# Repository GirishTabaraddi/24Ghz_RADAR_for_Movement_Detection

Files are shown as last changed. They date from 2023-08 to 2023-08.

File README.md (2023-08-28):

# 24Ghz_RADAR_for_Movement_Detection

This Project describes the Movement Detection using 24GHz CW-RADAR sensor which was performed in the System Driven Hardware Design Lab as a lab group.

KiCad_LabProject - This folder contains all the schematic and pcb files.
				 - 10_work folder contains the recent files of the project schematic.
				 - 20_release folder contains all the previous versions of the circuit design.

SDHD_PSoC_Codes - This folder contains all the project codes for various lab assigments and final code of the movement detector Project

SDHD_Lab3_FFT.cydsn - This workspace inside the SDHD_PSoC_Codes is the main code required for executing the Movement Detection.

Project Report pdf and ppt are added for reference to understand how the project was performed in the lab during summer semester.

This Project was carried at Hochschule Darmstadt during Summer semester 2023.
Other contributors are: Drashti Shah and Ananya Harish.

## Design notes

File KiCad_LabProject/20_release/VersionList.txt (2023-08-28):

17.04.2023, GROUP D3
Project: Movement Detector based on IPM-165 Radar Module
------------------------------------------------------------------------

17.04.2023 - Movement Detector based on IPM-165 Radar Module, Vesion 1.0
------------------------------------------------------------------------
Features:
		1. Schematic of 4th order Bandpass filter.
		2. Includes all the necessary calculations.
		3. Footprint Assignments to all the components.

19.04.2023 - Movement Detector based on IPM-165 Radar Module, Vesion 1.1
------------------------------------------------------------------------
Features:
		1. Schematic of 4th order Bandpass filter modified due 
			to mil errors in the previous schematic.
		2. Added Star ground connection, SW Push button and 
			90° 3 Pin connector.
		3. Necessary footprints assigned to all the components.

26.04.2023 - Movement Detector based on IPM-165 Radar Module, Vesion 1.2
------------------------------------------------------------------------
Features:
		1. Schematic of 4th order Bandpass filter modified as 
			per the feedback from first lab.
		2. Removed all ground differentiations like analog, 
			digital grounds and made only one commmon ground for all circuits.
		3. Removed star ground connection.
		4. Assigned correct footprints to all components as per the datasheets.
		5. Added +5v at all points.

03.05.2023 - Movement Detector based on IPM-165 Radar Module, Vesion 1.3
------------------------------------------------------------------------
Features:
		1. Few updates on the footprints.
		2. Placed all the components on PCB layout and routed all the components.
		3. Layer 1 and 4 are common ground.

13.05.2023 - Movement Detector based on IPM-165 Radar Module, Vesion 1.4
------------------------------------------------------------------------
Features:
		1. Replaced the components for better design and short distance
			from sensor to Vin.
		2. Added vias for GND.
		3. Connected SW_Push to GND (Pull-up network).
		4. Added +5V and GND naming to 3 Pin connector for better readability.

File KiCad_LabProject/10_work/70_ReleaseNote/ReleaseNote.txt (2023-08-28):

17.04.2023, GROUP D3
Project: Movement Detector based on IPM-165 Radar Module
---------------------------------------------------------------

v1.0: 17.04.2023
###############################################################
Features:
		1. Schematic of 4th order Bandpass filter.
		2. Includes all the necessary calculations.
		3. Footprint Assignments to all the components.
		 
v1.1: 19.04.2023
###############################################################
Features:
		1. Schematic of 4th order Bandpass filter modified due 
			to mil errors in the previous schematic.
		2. Added Star ground connection, SW Push button and 
			90° 3 Pin connector.
		3. Necessary footprints assigned to all the components.
		
v1.2: 26.04.2023
###############################################################
Features:
		1. Schematic of 4th order Bandpass filter modified as 
			per the feedback from first lab.
		2. Removed all ground differentiations like analog, 
			digital grounds and made only one commmon ground for all circuits.
		3. Removed star ground connection.
		4. Assigned correct footprints to all components as per the datasheets.
		5. Added +5v at all points.
		
v1.3 03.05.2023
###############################################################
Features:
		1. Few updates on the footprints.
		2. Placed all the components on PCB layout and routed all the components.
		3. Layer 1 and 4 are common ground.

v1.4 13.05.2023
###############################################################
Features:
		1. Replaced the components for better design and short distance
			from sensor to Vin.
		2. Added vias for GND.
		3. Connected SW_Push to GND (Pull-up network).
		4. Added +5V and GND naming to 3 Pin connector for better readability.

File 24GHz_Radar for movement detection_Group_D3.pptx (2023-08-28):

## 24GHz-Radar for movement detection

- Group number: d3
- Members:
Girish Tabaraddi 1119236
Drashti shah 1119295
Ananya harish 1119248

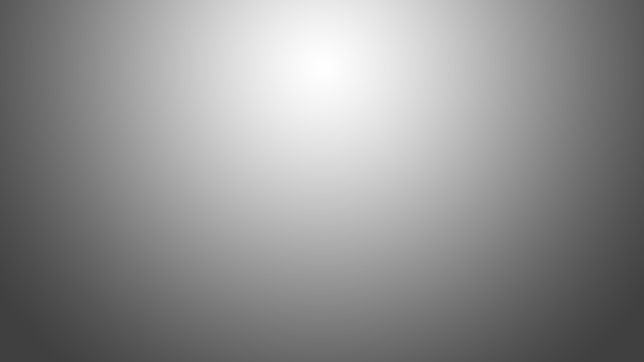
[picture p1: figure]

## Content

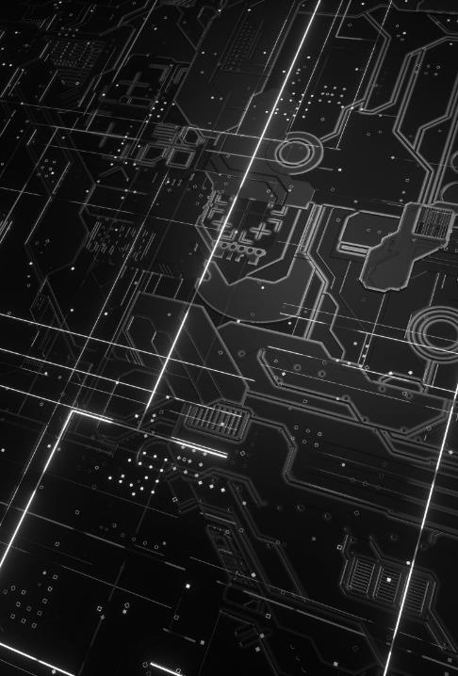
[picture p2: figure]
Abstract technological connection

- Introduction
- Block Diagram
- Schematic and PCB design
- 3D View and Soldered PCB
- State Machine
- Software Code
- Breadboard connections
- Hardware Testing
- CFAR algorithm

## INTRODUCTION:

- A 24 GHz radar sensor detects movements and send Doppler frequency to bandpass filter if the movement is detected.
- The 4th order Bandpass filter gives Baseband signal as the output which in-turn is send to the ADC.
- PSOC samples ADC and FFT data and sends it to MATLAB.
- We are using CFAR to set a threshold with which the probability of false alarm reduces.

## BLOCK DIAGRAM

RADAR MODULE

Amplifier

Band pass filter

ADC

LED

Detector

CFAR

FFT

## Schematic and pcb design

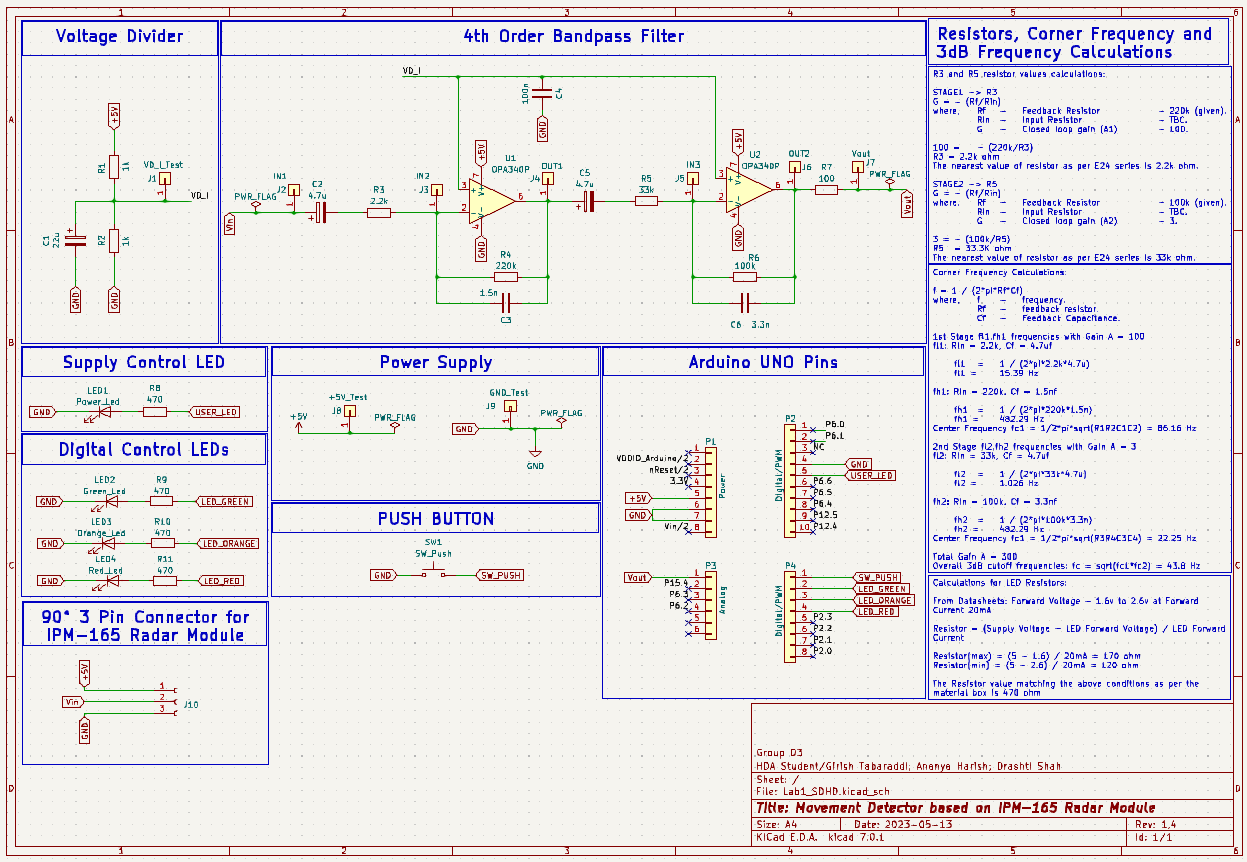
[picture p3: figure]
A computer screen shot of a diagram

Fig 1. PCB SCHEMATIC VIEW

## 3D view and soldered PCB

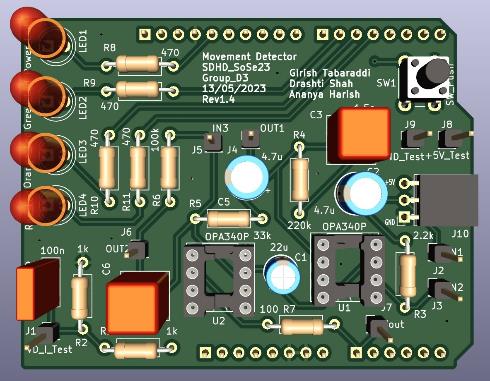
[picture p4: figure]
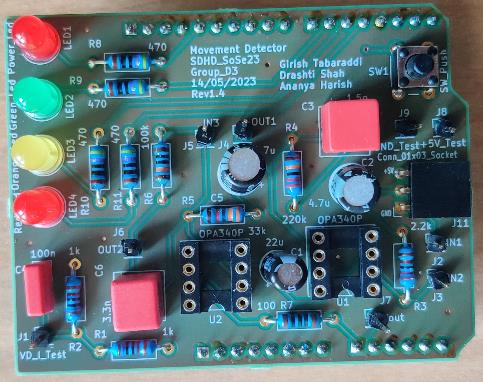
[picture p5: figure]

Fig 3. PCB TOP VIEW

Fig 2. PCB 3D VIEW

## STATE MACHINE

Fig 4. State Machine

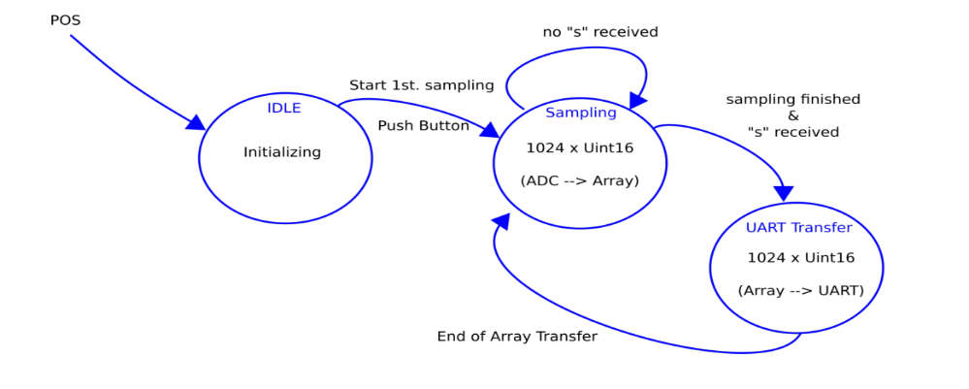
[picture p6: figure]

## SOFTWARE CODE

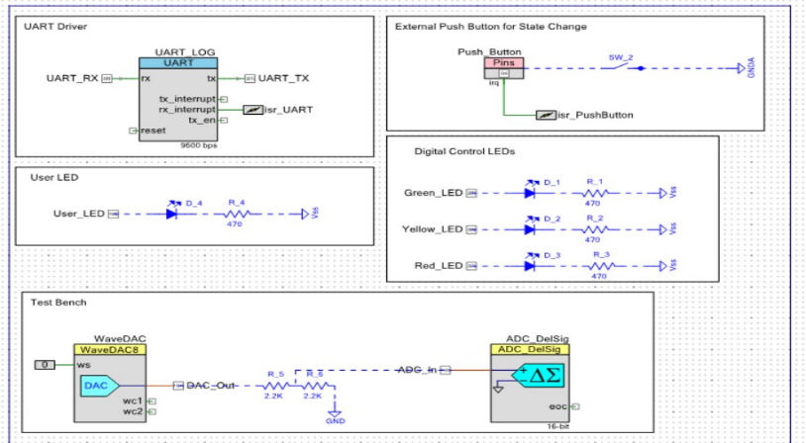
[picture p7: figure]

Fig 5. TOP DESIGN

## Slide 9

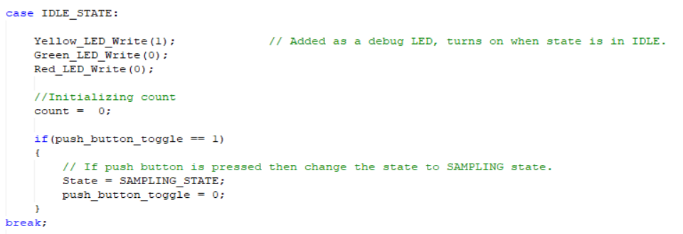
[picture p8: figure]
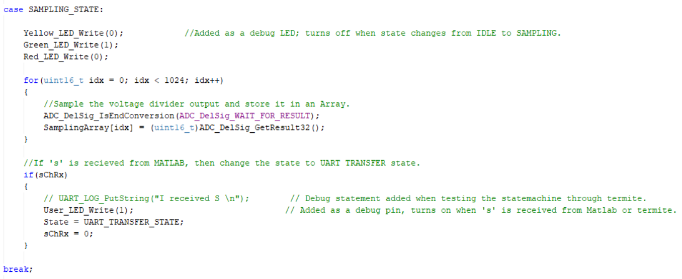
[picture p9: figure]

Fig 6. IDLE STATE

Fig 7. SAMPLING STATE

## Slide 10

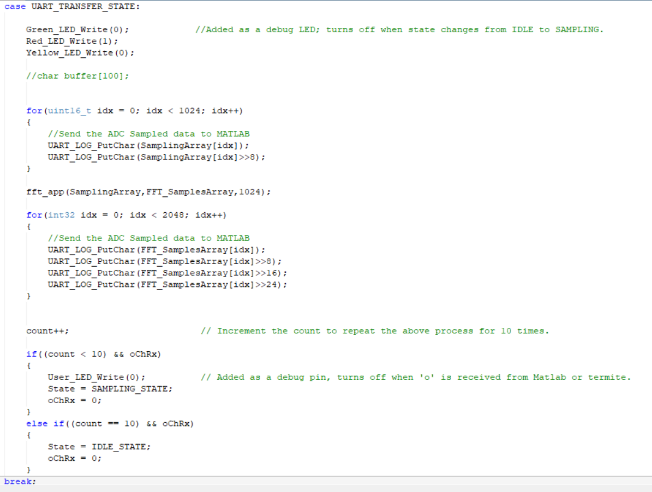
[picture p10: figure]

Fig 8. UART TRANSFER STATE

## Matlab output

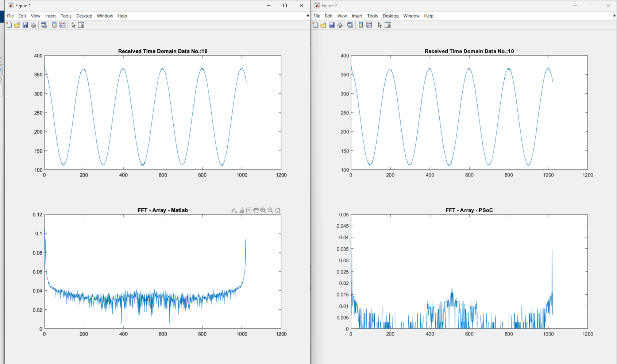
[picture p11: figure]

Fig 9. Matlab FFT Output

## Breadboard connections

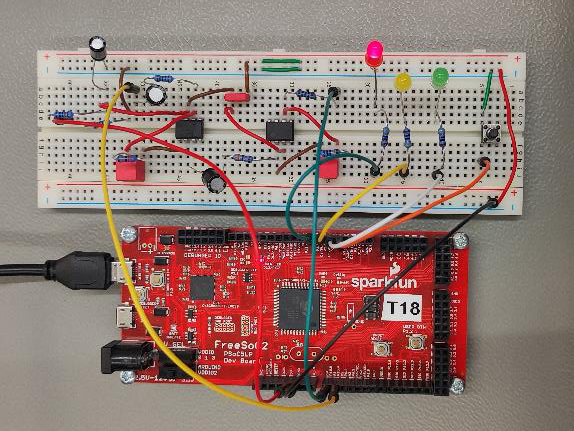
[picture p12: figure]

Fig 10. 4th Order Bandpass filter

## Hardware testing

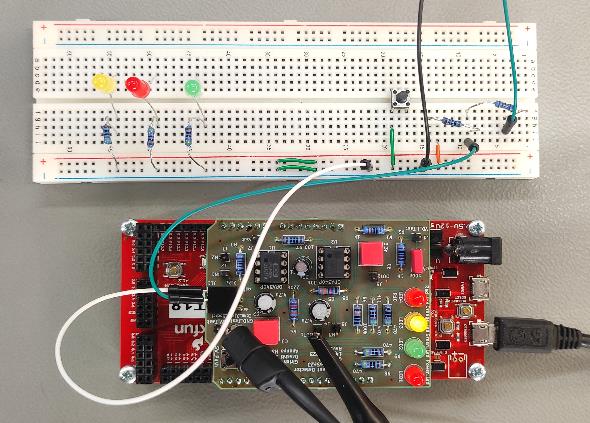
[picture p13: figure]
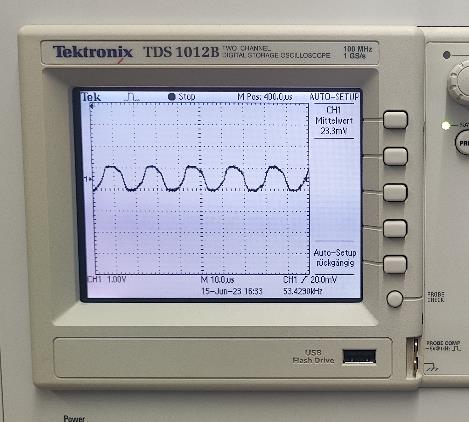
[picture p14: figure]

Fig 12. 1st Stage Circuit Output

Fig 11. 1st Stage Circuit

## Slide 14

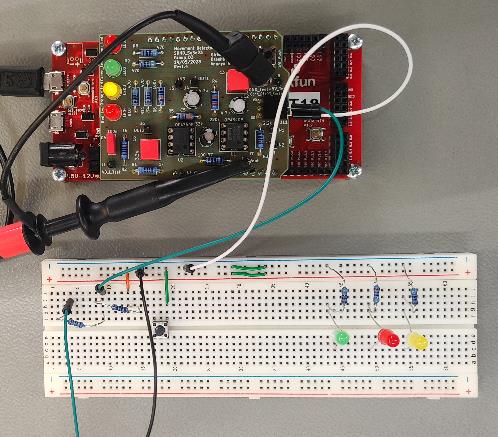
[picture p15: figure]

Fig 13. Final PCB Connection

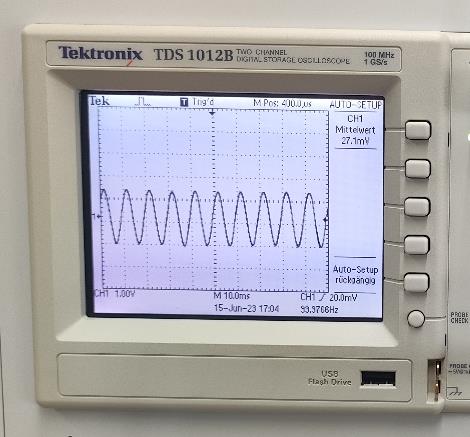
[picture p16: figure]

Fig 14. Final Output with Gain 300 dB

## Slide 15

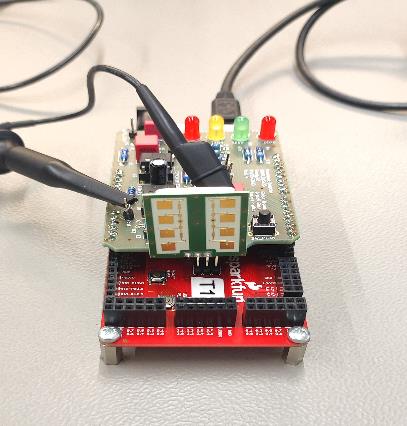
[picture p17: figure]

Fig 15. PCB with CW Radar Sensor

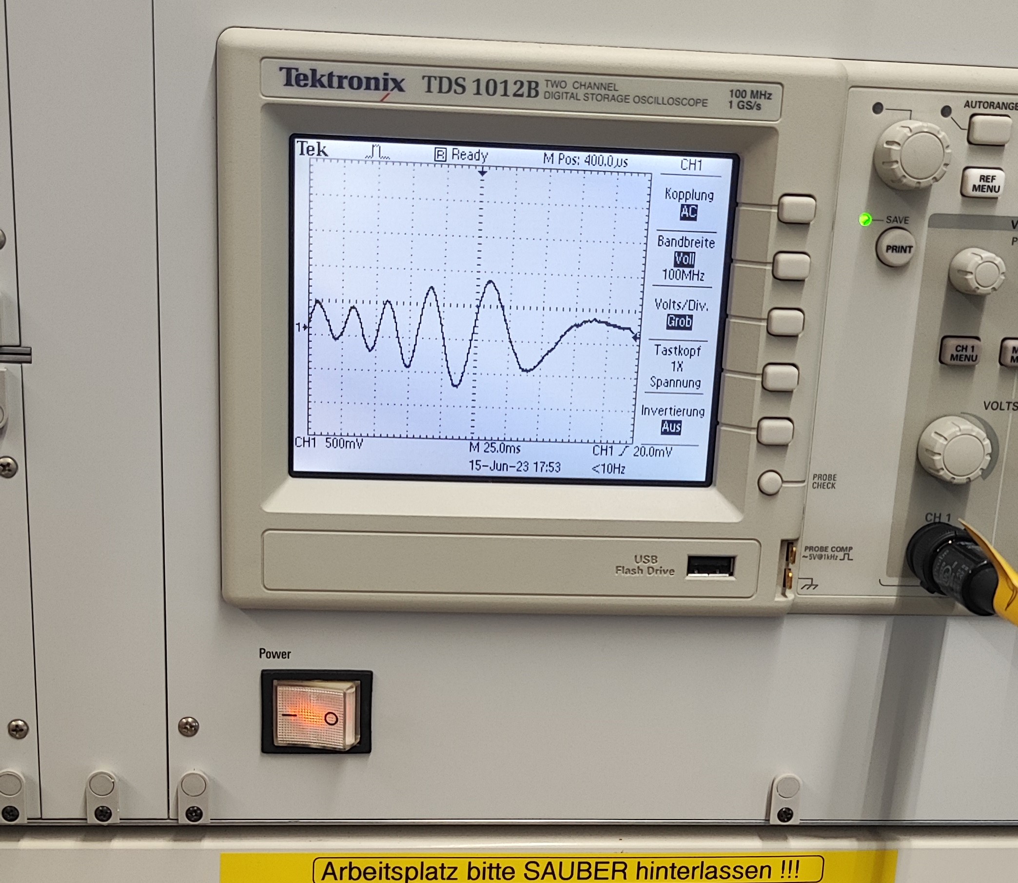
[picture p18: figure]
A white electronic device with a screen

Fig 16. Output

## CFAR Algorithm

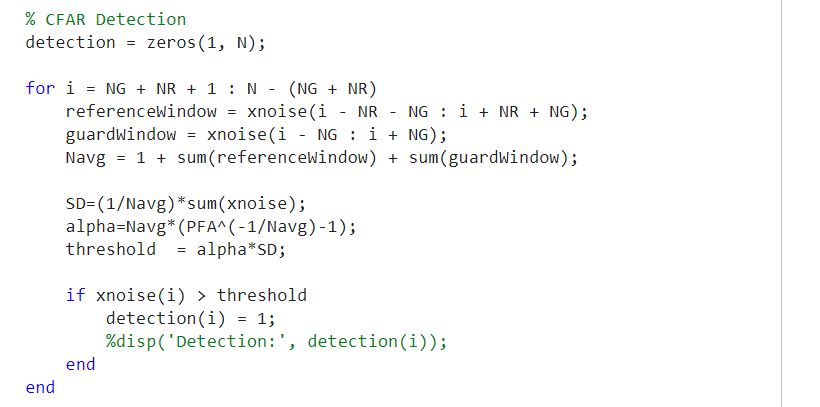
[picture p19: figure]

Fig 17. CFAR Algorithm

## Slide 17

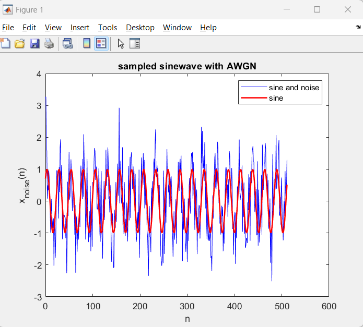
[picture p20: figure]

Fig 18. Signal+Noise

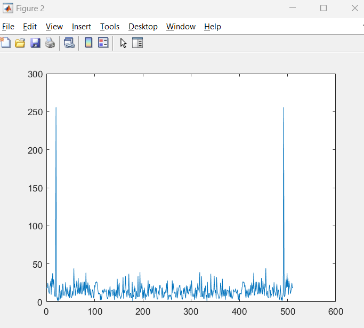
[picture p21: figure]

Fig 20. FFT of Signal+Noise

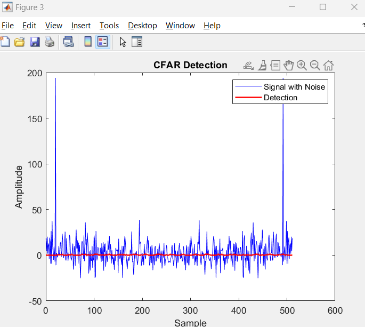
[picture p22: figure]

Fig 19. CFAR Detection

## THANK YOU

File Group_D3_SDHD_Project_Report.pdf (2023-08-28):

P r o j e c t R e p o r t
G r o u p D 3

2 4 G h z - R A D A R fo r
M o v e m e n t D e t e c t i o n

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

# 24Ghz-RADAR for Movement Detection Group D3 Project Documentation

Lab
Instructors: Mr. Holger Wech
Mr. Manuel Leidel

This Document describes the Movement Detection using 24GHz CW-RADAR sensor which was performed in the System Driven Hardware Design Lab as a lab group.

Author: | Ananya Harish | Communications | 1119248
Drashti Shah | Embedded Systems 1119295

Girish Tabaraddi Embedded Systems 1119236

Status: | released
Revision | Date | Editor | Reason
v1.0 | 02/July/2023 | Group D3 | Basic content and formatting

File: D3_SDHD_Project_Report | © Mimir – For Internal Use Only | Page 2 of 26
1.2.2 | 4

File: D3_SDHD_Project_Report | © Mimir – For Internal Use Only | Page 3 of 26


File: D3_SDHD_Project_Report | © Mimir – For Internal Use Only | Page 4 of 26

### 1 KiCad Schematic

The necessary schematic of Movement Detection using IPM-165 radar module is designed using KiCad 7.0 open-source free software.

### 1.1 Overall Schematic

- Clearly separated designs with Global Labels/Flags.
- Arduino shield was added for mounting of the amplifier on the FreeSoC board.
- 2 Stage Amplifier Design.
- Extra test points for easy debugging.
- LEDs to indicate the status of State Machine.

Fig.1 KiCad Schematic

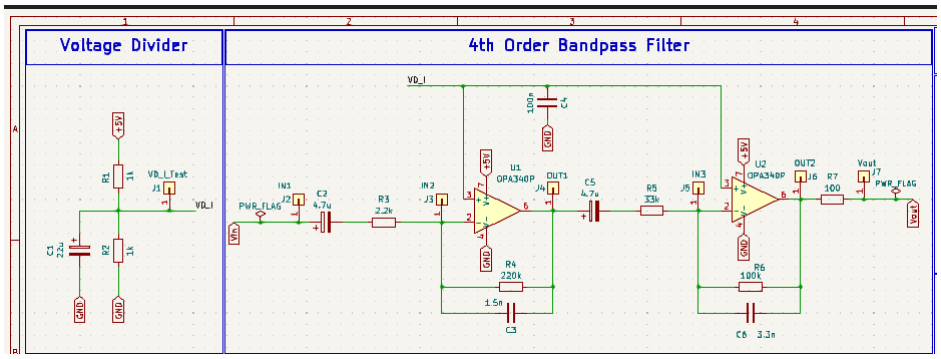
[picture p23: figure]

File: D3_SDHD_Project_Report | © Mimir – For Internal Use Only | Page 5 of 26

### 1.2 Analog Circuit

Fig 2. Voltage Divider and Bandpass Filter

### 1.2.1 Voltage Divider Circuit

Voltage Divider circuit is used to cut down the 5V given from the FreeSoC board to the non-inverting terminals of both the op-amps U1 & U2. The voltage is reduced to 2.5V, because the resistors selected have equal value (1kΩ each).

1.2.2 4

th Order Bandpass Filter

Vin (output of the radar module) is fed as the input to inverting terminal of the OPA-340 U1. The voltage range of the radar sensor is -300mV to 300mV. The circuit is designed to have a total gain of 300, which is divided into gain of 100 for the first stage amplifier and a gain of 3 for the second stage of the amplifier. Each of the circuit stages has their own test points for easy debugging and testing. The output of the amplifier circuit is passed on to the 16-bit ADC of PSOC board.

Fig 3. R3 and R5 resistor calculations.

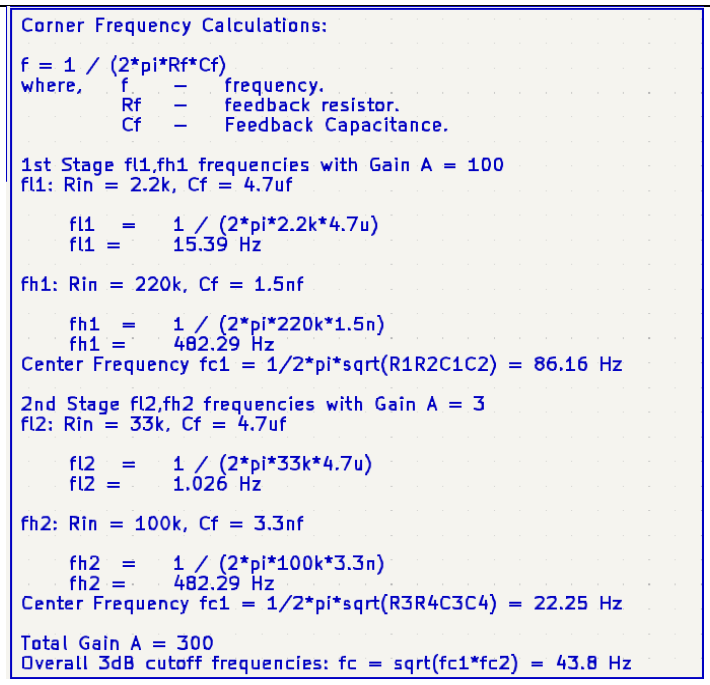
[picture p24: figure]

File: D3_SDHD_Project_Report | © Mimir – For Internal Use Only | Page 6 of 26

Fig 4. Corner Frequency Calculations.

### 1.3 Digital Circuit

Push Button is used to change from initial state to sampling state in software implementation, which is explained later in the following sections.
Similarly, the LEDs are added to visually notice the change of states. The Supply control LED is added in the design to ensure that the PCB is powered up.
Fig 5. Push Button. | Fig 6. Digital LEDs for State-machine.


File: D3_SDHD_Project_Report | © Mimir – For Internal Use Only | Page 7 of 26

Fig 7. LED Resistor Calculations.

### 1.4 Power Supply

Power flags and global naming flags ared added for convenience. Sufficient test points are added in the circuit for easy debugging and testing.

Fig 8. Power Supply Connection.


File: D3_SDHD_Project_Report | © Mimir – For Internal Use Only | Page 8 of 26

### 1.5 IPM-165 Radar Module

The IPM-165 is a 24GHz doppler module with an asymmetrical wide beam for detection of moving objects. Pin 1 of the sensor is used to power up the radar module, Pin 2 is used to give input to the bandpass filter and Pin 3 is connected to the ground.

Fig 9. IPM-165 Radar Module

### 1.6 Interface to FreeSoC Board

To integrate our circuit to the FreeSoC board, we need the Arduino UNO shield which matches the FreeSoC pins. So, we imported the Arduino UNO shield from KiCad inbuilt library and the necessary pin mapping is provided in the following figure.

Fig 10. Arduino UNO Shield pin mapping.


File: D3_SDHD_Project_Report | © Mimir – For Internal Use Only | Page 9 of 26

### 2 PCB Design

### 2.1 About PCB

Our PCB has a thickness of 1.6mm and consists of four layers. Four layers PCB means there are 4 layers to rout electrical signals: Top Layer, Inner Layer 1, Inner Layer 2 and Bottom Layer. TOP and bottom layers are the outer layers where we are placing components and routing. Inner layer 1 and inner layer 2 are in the core, and normally used as power planes or used for signal routing. Therefore, 4-layer PCB = 3 Signal layer + GND layer or 4-layer PCB = 2 signal layers + a VCC layer + a GND layer [Reference: https://www.allpcb.com/4_layer_pcb.html].

### 2.2 Layer 1

On this layer all signals and the components are placed. On the top and bottom layer, ground is poured to provide insulation. Vias are added to connect the ground layers on top and bottom together.

Fig 11. Front Signal Layer with routing


File: D3_SDHD_Project_Report | © Mimir – For Internal Use Only | Page 10 of 26

### 2.3 Layer 2

Ground is poured here.

Fig 12. Ground Layer

### 2.4 Layer 3

Here the VCC is poured over the third layer.

Fig 13. Power Layer


File: D3_SDHD_Project_Report | © Mimir – For Internal Use Only | Page 11 of 26

### 2.5 Layer 4

In order to avoid crossings of routing in first layer, the crossings are connected in the fourth layer. Vias are added to connect first and fourth layer.

Fig 14. Bottom Signal Layer with routing

2.6 3D view of PCB

The 3D view of the designed PCB is shown in the below figure. The minimum tract length between the input of the Radar and to the input of the IC is worked out.

Fig 15. 3D View

### 3 Hardware Connections


File: D3_SDHD_Project_Report | © Mimir – For Internal Use Only | Page 12 of 26

### 3.1 Stage 1 circuit connection

The connections of the first stage from the PCB are verified at test point J4(OUT1). An additional voltage divider circuit is connected to the PCB externally in order to reduce the input voltage such that the output voltage remains in the given range. For testing, we considered Vin of 200mV which was cut down to 8mV using resistors of 2.2kΩ and 100Ω. The gain of the first stage designed is 100 and the same was verified by obtaining an output voltage of 0.8V. The connection and output are as shown below.

Fig 16. First stage connection.

Fig 17. First stage output.


File: D3_SDHD_Project_Report | © Mimir – For Internal Use Only | Page 13 of 26

3.2 2 Stage circuit connection

The connections of the second stage from the PCB are verified at test point J7(VOUT). For the Vin of 200mV which was cut down to 8mV using resistors of 2.2kΩ and 100Ω at first stage. For the second stage with design of gain 3, the output was verified by obtaining 2.4V output voltage. The connection and output are as shown below.

Fig 18. Second stage connection.

Fig 19. Second stage output.


File: D3_SDHD_Project_Report | © Mimir – For Internal Use Only | Page 14 of 26

### 3.3 PCB with IPM-165 Radar Module

The IPM-165 Radar module is connected to the working PCB in order to detect the movement of a moving object. From the output it can be observed that the movement is detected by change of frequency as well as amplitude of the signal.

Fig 20. PCB with radar module

Fig 21. Radar module output

### 4 Software


File: D3_SDHD_Project_Report | © Mimir – For Internal Use Only | Page 15 of 26

### 4.1 Top Design for State-machine

Fig 22. Top Design

Fig 23. Pin mapping


File: D3_SDHD_Project_Report | © Mimir – For Internal Use Only | Page 16 of 26

### 4.1.1 ADC

Fig 24. ADC Configuration

### 4.1.2 DAC

Fig 25. DAC Configuration


File: D3_SDHD_Project_Report | © Mimir – For Internal Use Only | Page 17 of 26

### 4.1.3 UART

Fig 26. UART Configuration

### 4.2 State Diagram

Fig 27. State Diagram


File: D3_SDHD_Project_Report | © Mimir – For Internal Use Only | Page 18 of 26

### 4.3 State-machine Code

### 4.3.1 Hardware Initialization

Fig 28. Hardware Init Function

### 4.3.2 ISR functions

Fig 29. ISR Function definiton


File: D3_SDHD_Project_Report | © Mimir – For Internal Use Only | Page 19 of 26

### 4.3.3 Idle State

Fig 30. Idle State logic

### 4.3.4 Sampling State

Fig 31. Sampling State logic


File: D3_SDHD_Project_Report | © Mimir – For Internal Use Only | Page 20 of 26

### 4.3.5 UART Transfer State

Fig 32. UART Transfer State logic


File: D3_SDHD_Project_Report | © Mimir – For Internal Use Only | Page 21 of 26

### 4.4 Matlab Code & Output

Fig 33. MATLAB Script

Fig 34. MATLAB FFT Output

### 5 CFAR Algorithm


File: D3_SDHD_Project_Report | © Mimir – For Internal Use Only | Page 22 of 26

### 5.1 Target detection

A threshold is calculated and set in order to detect a signal and differentiate it with respect to noise. This in turn is used to reduce the probability of false alarm detection.

The following probabilities are used:
PD: A target is declared when a target is in fact present – Detection.
PM: A target is not declared when a target is in fact present – Missed. PFA: A target is declared when a target is in fact not present – False alarm.

Formula to calculate threshold:

The probability of detection is calculated using:

### 5.2 CFAR Code

Fig 35. CFAR Algorithm Script


File: D3_SDHD_Project_Report | © Mimir – For Internal Use Only | Page 23 of 26

### 5.3 CFAR Output

Fig 36. Signal + Noise Waveform

Fig 37. FFT of Signal + Noise


File: D3_SDHD_Project_Report | © Mimir – For Internal Use Only | Page 24 of 26

Fig 38. CFAR Detection

### 6 Manufactured & Soldered PCB


File: D3_SDHD_Project_Report | © Mimir – For Internal Use Only | Page 25 of 26

Fig 39. Unsoldered PCB

Fig 40. Soldered PCB Top View

File: D3_SDHD_Project_Report | © Mimir – For Internal Use Only | Page 26 of 26

### 7 References:

1. SDHD Lecture Slides
2. www.mathworks.com
3. https://mimir.h-da.io/public/index.htm
4. PSoC Getting Started by Thomas Barth
5. Embedded Architectures and Operating Systems Workbook (v2020a) by Prof. Dr.-Ing. Peter Fromm
6. https://www.sparkfun.com/products/13714
7. https://www.infineon.com/dgdl/Infineon-KitProg_User_Guide-UserManual-v01_00-EN.pdf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

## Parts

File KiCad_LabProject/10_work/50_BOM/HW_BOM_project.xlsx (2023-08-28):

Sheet: History
<Template Name - Achtung: Header und Footer Setzen>
<Department>
<ProjectName>
Author: | Name/Department
Status: | draft/release/obsolete
History
Revision | Date | Author | Reason

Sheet: Instructions
Field | Description

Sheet: content_page
Date: | 2023-05-03 12:16
Revision: | 1.3
Component Count: | 3
Number of Boards: | 6.00
 | Single Board |  |  |  | Order |  |  |  | Notes
Ref | Value | Qnty | Vendor | Order No. | Component Name | Order Qnty | single price | Total price | Footprint | Description
C1 | 22u | 1 | Reichelt | RAD FR 22/50 | C_Polarized | 1 | 0.08 € | 0.08 € | Capacitor_THT:CP_Radial_D5.0mm_P2.50mm | Polarized capacitor
C2, C5 | 4.7u | 2 | Reichelt | SM 4,7/50RAD | C_Polarized | 2 | 0.08 € | 0.16 € | Capacitor_THT:CP_Radial_D6.3mm_P2.50mm | Polarized capacitor
C3 | 1.5n | 1 | Reichelt | FKP2-1000 1,5N | C | 1 | 0.08 € | 0.08 € | Capacitor_THT:C_Rect_L7.2mm_W7.2mm_P5.00mm_FKS2_FKP2_MKS2_MKP2 | Unpolarized capacitor
C4 | 100n | 1 | Reichelt | MKS2-100 100N | C | 1 | 0.08 € | 0.08 € | Capacitor_THT:C_Rect_L7.2mm_W2.5mm_P5.00mm_FKS2_FKP2_MKS2_MKP2 | Unpolarized capacitor
C6 | 3.3n | 1 | Reichelt | FKP2-630 3,3N | C | 1 | 0.08 € | 0.08 € | Capacitor_THT:C_Rect_L7.2mm_W7.2mm_P5.00mm_FKS2_FKP2_MKS2_MKP2 | Unpolarized capacitor
J1, J2 | ~ | 2 |  |  | Conn_01x01 | 2 |  |  | Connector_PinHeader_2.54mm:PinHeader_1x01_P2.54mm_Vertical | Generic connector, single row, 01x01, script generated (kicad-library-utils/schlib/autogen/connector/)
J3 | IN1 | 1 |  |  | Conn_01x01 | 1 |  |  | Connector_PinHeader_2.54mm:PinHeader_1x01_P2.54mm_Vertical | Generic connector, single row, 01x01, script generated (kicad-library-utils/schlib/autogen/connector/)
J4 | IN2 | 1 |  |  | Conn_01x01 | 1 |  |  | Connector_PinHeader_2.54mm:PinHeader_1x01_P2.54mm_Vertical | Generic connector, single row, 01x01, script generated (kicad-library-utils/schlib/autogen/connector/)
J5 | OUT1 | 1 |  |  | Conn_01x01 | 1 |  |  | Connector_PinHeader_2.54mm:PinHeader_1x01_P2.54mm_Vertical | Generic connector, single row, 01x01, script generated (kicad-library-utils/schlib/autogen/connector/)
J6 | IN3 | 1 |  |  | Conn_01x01 | 1 |  |  | Connector_PinHeader_2.54mm:PinHeader_1x01_P2.54mm_Vertical | Generic connector, single row, 01x01, script generated (kicad-library-utils/schlib/autogen/connector/)
J7 | OUT2 | 1 |  |  | Conn_01x01 | 1 |  |  | Connector_PinHeader_2.54mm:PinHeader_1x01_P2.54mm_Vertical | Generic connector, single row, 01x01, script generated (kicad-library-utils/schlib/autogen/connector/)
J8 | Vout | 1 |  |  | Conn_01x01 | 1 |  |  | Connector_PinHeader_2.54mm:PinHeader_1x01_P2.54mm_Vertical | Generic connector, single row, 01x01, script generated (kicad-library-utils/schlib/autogen/connector/)
J9 | +5V_Test | 1 |  |  | Conn_01x01 | 1 |  |  | Connector_PinHeader_2.54mm:PinHeader_1x01_P2.54mm_Vertical | Generic connector, single row, 01x01, script generated (kicad-library-utils/schlib/autogen/connector/)
J10 | GND_Test | 1 |  |  | Conn_01x01 | 1 |  |  | Connector_PinHeader_2.54mm:PinHeader_1x01_P2.54mm_Vertical | Generic connector, single row, 01x01, script generated (kicad-library-utils/schlib/autogen/connector/)
J11 | Conn_01x03_Socket | 1 |  |  | Conn_01x03_Socket | 1 |  |  | Connector_PinSocket_2.54mm:PinSocket_1x03_P2.54mm_Horizontal | Generic connector, single row, 01x03, script generated
LED1 | Power_Led | 1 | Distrelec | 301-32-217 | LED | 1 |  |  | LED_THT:LED_D5.0mm | Light emitting diode
LED2 | Green_Led | 1 | Distrelec | 301-32-225 | LED | 1 |  |  | LED_THT:LED_D5.0mm | Light emitting diode
LED3 | Orange_Led | 1 | Distrelec | 301-32-218 | LED | 1 |  |  | LED_THT:LED_D5.0mm | Light emitting diode
LED4 | Red_Led | 1 | Distrelec | 301-32-217 | LED | 1 |  |  | LED_THT:LED_D5.0mm | Light emitting diode
P1 | Power | 1 |  |  | Conn_01x08 | 1 |  |  | Connector_PinSocket_2.54mm:PinSocket_1x08_P2.54mm_Vertical | Generic connector, single row, 01x08, script generated (kicad-library-utils/schlib/autogen/connector/)
P2 | Digital/PWM | 1 |  |  | Conn_01x10 | 1 |  |  | Connector_PinSocket_2.54mm:PinSocket_1x10_P2.54mm_Vertical | Generic connector, single row, 01x10, script generated (kicad-library-utils/schlib/autogen/connector/)
P3 | Analog | 1 |  |  | Conn_01x06 | 1 |  |  | Connector_PinSocket_2.54mm:PinSocket_1x06_P2.54mm_Vertical | Generic connector, single row, 01x06, script generated (kicad-library-utils/schlib/autogen/connector/)
P4 | Digital/PWM | 1 |  |  | Conn_01x08 | 1 |  |  | Connector_PinSocket_2.54mm:PinSocket_1x08_P2.54mm_Vertical | Generic connector, single row, 01x08, script generated (kicad-library-utils/schlib/autogen/connector/)
R1, R2 | 1k | 2 | Reichelt | METALL 1,00K | R | 2 | 0.17 € | 0.34 € | Resistor_THT:R_Axial_DIN0207_L6.3mm_D2.5mm_P10.16mm_Horizontal | Resistor
R3 | 2.2k | 1 | Reichelt | METALL 2,20K | R | 1 | 0.17 € | 0.17 € | Resistor_THT:R_Axial_DIN0207_L6.3mm_D2.5mm_P10.16mm_Horizontal | Resistor
R4 | 220k | 1 | Reichelt | METALL 220K | R | 1 | 0.10 € | 0.10 € | Resistor_THT:R_Axial_DIN0207_L6.3mm_D2.5mm_P10.16mm_Horizontal | Resistor
R5 | 33k | 1 | Reichelt | METALL 33,0K | R | 1 | 0.17 € | 0.17 € | Resistor_THT:R_Axial_DIN0207_L6.3mm_D2.5mm_P10.16mm_Horizontal | Resistor
R6 | 100k | 1 | Reichelt | METALL 100K | R | 1 | 0.17 € | 0.17 € | Resistor_THT:R_Axial_DIN0207_L6.3mm_D2.5mm_P10.16mm_Horizontal | Resistor
R7 | 100 | 1 | Reichelt | METALL 100 | R | 1 | 0.17 € | 0.17 € | Resistor_THT:R_Axial_DIN0207_L6.3mm_D2.5mm_P10.16mm_Horizontal | Resistor
R8, R9, R10, R11 | 470 | 4 | Reichelt | METALL 470 | R | 4 | 0.17 € | 0.68 € | Resistor_THT:R_Axial_DIN0207_L6.3mm_D2.5mm_P10.16mm_Horizontal | Resistor
SW1 | SW_Push | 1 | Distrelec | 300-90-650 | SW_Push | 1 |  |  | Button_Switch_THT:SW_PUSH_6mm_H7.3mm | Push button switch, generic, two pins
U1, U2 | OPA340P | 2 | Mouser | 595-OPA340PA | OPA340P | 2 |  |  | Package_DIP:DIP-8_W7.62mm_Socket | Single Single-Supply, Rail-to-Rail Operational Amplifier, MicroAmplifier Series, DIP-8

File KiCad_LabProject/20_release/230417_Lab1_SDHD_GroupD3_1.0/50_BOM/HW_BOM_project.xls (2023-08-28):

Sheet: History
<Template Name - Achtung: Header und Footer Setzen>
<Department>
<ProjectName>
Author: | Name/Department
Status: | draft/release/obsolete
History
Revision | Date | Author | Reason

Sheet: Instructions
Field | Description

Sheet: content_page
Date: | 2020-03-05 12:16
Revision: | 1.0
Component Count: | 3
Number of Boards: | 6.00
 | Single Board |  |  |  | Order |  |  |  |  | Notes
Ref | Value | Qnty | Vendor | Order No. | Component Name | Order Qnty | single price | Total price | Cmp name | Footprint | Description
C1, C2, | 100n | 2.00 | Conrad | 1235240 - 62 | Kemet, 100 nF 63 V 10 % 5 mm (L x B x H) 7.2 x 2.5 mm x 6.5 mm | 12 | 0.08 € | 0.96 | C | Capacitor_THT:C_Rect_L7.2mm_W2.5mm_P5.00mm_FKS2_FKP2_MKS2_MKP2 | Unpolarized capacitor
R1, R2, | 15k | 2.00 | on Stock |  |  | 12 |  | 0.00 | R | Resistor_THT:R_Axial_DIN0204_L3.6mm_D1.6mm_P7.62mm_Horizontal | Resistor
U1, | NE555 | 1.00 | Reichelt | NE 555 DIP | NE 555 DIP Timer-IC, Typ 555, DIP-8 | 6 | 0.17 € | 1.02 | NE555 | Package_DIP:DIP-8_W7.62mm_Socket | Precision Timers, DIP-8/SOIC-8
 |  |  |  |  |  | 0 |  | 0.00
 |  |  |  |  |  |  | Total costs: | 1.98

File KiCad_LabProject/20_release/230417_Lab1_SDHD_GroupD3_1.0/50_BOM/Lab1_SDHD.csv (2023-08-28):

Source: | G:\HP_Backup\SDHD\Labor\LabProject\40_Implementation\10_HW\XX_PCB_template\10_work\80_ProjectFiles\Lab1_SDHD\Lab1_SDHD.kicad_sch
Date: | 16/04/2023 23:56:01
Tool: | Eeschema 7.0.1
Generator: | C:\Program Files\KiCad\7.0\bin\scripting\plugins/bom_csv_grouped_by_value_with_fp.py
Component Count: | 38
Ref | Qnty | Value | Cmp name | Footprint | Description | Vendor | DNP
C1 | 1 | 22u | C_Polarized | Capacitor_THT:CP_Radial_D5.0mm_P2.50mm | Polarized capacitor
C2, C5 | 2 | 4.7u | C_Polarized | Capacitor_THT:CP_Radial_D5.0mm_P2.50mm | Polarized capacitor
C3 | 1 | 1.5n | C | Capacitor_THT:C_Disc_D4.3mm_W1.9mm_P5.00mm | Unpolarized capacitor
C4 | 1 | 100n | C | Capacitor_THT:C_Disc_D4.3mm_W1.9mm_P5.00mm | Unpolarized capacitor
C6 | 1 | 3.3n | C | Capacitor_THT:C_Disc_D4.3mm_W1.9mm_P5.00mm | Unpolarized capacitor
J1 | 1 | ~ | Conn_01x01 | Connector_Pin:Pin_D1.0mm_L10.0mm | Generic connector, single row, 01x01, script generated (kicad-library-utils/schlib/autogen/connector/)
J2 | 1 | Vin | Conn_01x01 | Connector_Pin:Pin_D1.0mm_L10.0mm | Generic connector, single row, 01x01, script generated (kicad-library-utils/schlib/autogen/connector/)
J3 | 1 | IN1 | Conn_01x01 | Connector_Pin:Pin_D1.0mm_L10.0mm | Generic connector, single row, 01x01, script generated (kicad-library-utils/schlib/autogen/connector/)
J4 | 1 | IN2 | Conn_01x01 | Connector_Pin:Pin_D1.0mm_L10.0mm | Generic connector, single row, 01x01, script generated (kicad-library-utils/schlib/autogen/connector/)
J5 | 1 | OUT1 | Conn_01x01 | Connector_Pin:Pin_D1.0mm_L10.0mm | Generic connector, single row, 01x01, script generated (kicad-library-utils/schlib/autogen/connector/)
J6 | 1 | IN3 | Conn_01x01 | Connector_Pin:Pin_D1.0mm_L10.0mm | Generic connector, single row, 01x01, script generated (kicad-library-utils/schlib/autogen/connector/)
J7 | 1 | OUT2 | Conn_01x01 | Connector_Pin:Pin_D1.0mm_L10.0mm | Generic connector, single row, 01x01, script generated (kicad-library-utils/schlib/autogen/connector/)
J8 | 1 | Vout | Conn_01x01 | Connector_Pin:Pin_D1.0mm_L10.0mm | Generic connector, single row, 01x01, script generated (kicad-library-utils/schlib/autogen/connector/)
J9 | 1 | GNDA | Conn_01x01 | Connector_Pin:Pin_D1.0mm_L10.0mm | Generic connector, single row, 01x01, script generated (kicad-library-utils/schlib/autogen/connector/)
J10 | 1 | GNDD | Conn_01x01 | Connector_Pin:Pin_D1.0mm_L10.0mm | Generic connector, single row, 01x01, script generated (kicad-library-utils/schlib/autogen/connector/)
J11 | 1 | VCC | Conn_01x01 | Connector_Pin:Pin_D1.0mm_L10.0mm | Generic connector, single row, 01x01, script generated (kicad-library-utils/schlib/autogen/connector/)
LED1 | 1 | Power_Led | LED | Diode_SMD:D_1206_3216Metric_Pad1.42x1.75mm_HandSolder | Light emitting diode
LED2 | 1 | Green_Led | LED | Diode_SMD:D_1206_3216Metric_Pad1.42x1.75mm_HandSolder | Light emitting diode
LED3 | 1 | Orange_Led | LED | Diode_SMD:D_1206_3216Metric_Pad1.42x1.75mm_HandSolder | Light emitting diode
LED4 | 1 | Red_Led | LED | Diode_SMD:D_1206_3216Metric_Pad1.42x1.75mm_HandSolder | Light emitting diode
P1 | 1 | Power | Conn_01x08 | Connector_PinSocket_2.54mm:PinSocket_1x08_P2.54mm_Vertical | Generic connector, single row, 01x08, script generated (kicad-library-utils/schlib/autogen/connector/)
P2 | 1 | Digital/PWM | Conn_01x10 | Connector_PinSocket_2.54mm:PinSocket_1x10_P2.54mm_Vertical | Generic connector, single row, 01x10, script generated (kicad-library-utils/schlib/autogen/connector/)
P3 | 1 | Analog | Conn_01x06 | Connector_PinSocket_2.54mm:PinSocket_1x06_P2.54mm_Vertical | Generic connector, single row, 01x06, script generated (kicad-library-utils/schlib/autogen/connector/)
P4 | 1 | Digital/PWM | Conn_01x08 | Connector_PinSocket_2.54mm:PinSocket_1x08_P2.54mm_Vertical | Generic connector, single row, 01x08, script generated (kicad-library-utils/schlib/autogen/connector/)
R1, R2 | 2 | ~ | R | Resistor_THT:R_Axial_DIN0204_L3.6mm_D1.6mm_P5.08mm_Horizontal | Resistor
R3 | 1 | 2.2k | R | Resistor_THT:R_Axial_DIN0204_L3.6mm_D1.6mm_P5.08mm_Horizontal | Resistor
R4 | 1 | 220k | R | Resistor_THT:R_Axial_DIN0204_L3.6mm_D1.6mm_P5.08mm_Horizontal | Resistor
R5 | 1 | 33k | R | Resistor_THT:R_Axial_DIN0204_L3.6mm_D1.6mm_P5.08mm_Horizontal | Resistor
R6 | 1 | 100k | R | Resistor_THT:R_Axial_DIN0204_L3.6mm_D1.6mm_P5.08mm_Horizontal | Resistor
R7 | 1 | 100 | R | Resistor_THT:R_Axial_DIN0204_L3.6mm_D1.6mm_P5.08mm_Horizontal | Resistor
R8, R9, R10, R11 | 4 | 330 | R | Resistor_THT:R_Axial_DIN0204_L3.6mm_D1.6mm_P5.08mm_Horizontal | Resistor
U1, U2 | 2 | OPA340P | OPA340P | Package_DIP:DIP-8_W7.62mm | Single Single-Supply, Rail-to-Rail Operational Amplifier, MicroAmplifier Series, DIP-8

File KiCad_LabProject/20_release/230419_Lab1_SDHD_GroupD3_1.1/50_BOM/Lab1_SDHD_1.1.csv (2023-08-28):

Source: | C:\HDA_Courses\Sem2\SDHD\Labor\LabProject\40_Implementation\10_HW\XX_PCB_template\10_work\80_ProjectFiles\Lab1_SDHD_New\Lab1_SDHD_New.kicad_sch
Date: | 21-04-2023 10:27:37
Tool: | Eeschema 7.0.1
Generator: | C:\Program Files\KiCad\7.0\bin\scripting\plugins/bom_csv_grouped_by_value_with_fp.py
Component Count: | 42
Ref | Qnty | Value | Cmp name | Footprint | Description | Vendor | DNP
C1 | 1 | 22u | C_Polarized | Capacitor_THT:CP_Radial_D5.0mm_P2.50mm | Polarized capacitor
C2, C5 | 2 | 4.7u | C_Polarized | Capacitor_THT:CP_Radial_D5.0mm_P2.50mm | Polarized capacitor
C3 | 1 | 1.5n | C | Capacitor_THT:C_Disc_D4.3mm_W1.9mm_P5.00mm | Unpolarized capacitor
C4 | 1 | 100n | C | Capacitor_THT:C_Disc_D4.3mm_W1.9mm_P5.00mm | Unpolarized capacitor
C6 | 1 | 3.3n | C | Capacitor_THT:C_Disc_D4.3mm_W1.9mm_P5.00mm | Unpolarized capacitor
J1, J2 | 2 | ~ | Conn_01x01 | Connector_Pin:Pin_D1.2mm_L10.2mm_W2.9mm_FlatFork | Generic connector, single row, 01x01, script generated (kicad-library-utils/schlib/autogen/connector/)
J3 | 1 | IN1 | Conn_01x01 | Connector_Pin:Pin_D1.2mm_L10.2mm_W2.9mm_FlatFork | Generic connector, single row, 01x01, script generated (kicad-library-utils/schlib/autogen/connector/)
J4 | 1 | IN2 | Conn_01x01 | Connector_Pin:Pin_D1.2mm_L10.2mm_W2.9mm_FlatFork | Generic connector, single row, 01x01, script generated (kicad-library-utils/schlib/autogen/connector/)
J5 | 1 | OUT1 | Conn_01x01 | Connector_Pin:Pin_D1.2mm_L10.2mm_W2.9mm_FlatFork | Generic connector, single row, 01x01, script generated (kicad-library-utils/schlib/autogen/connector/)
J6 | 1 | IN3 | Conn_01x01 | Connector_Pin:Pin_D1.2mm_L10.2mm_W2.9mm_FlatFork | Generic connector, single row, 01x01, script generated (kicad-library-utils/schlib/autogen/connector/)
J7 | 1 | OUT2 | Conn_01x01 | Connector_Pin:Pin_D1.2mm_L10.2mm_W2.9mm_FlatFork | Generic connector, single row, 01x01, script generated (kicad-library-utils/schlib/autogen/connector/)
J8 | 1 | Vout | Conn_01x01 | Connector_Pin:Pin_D1.2mm_L10.2mm_W2.9mm_FlatFork | Generic connector, single row, 01x01, script generated (kicad-library-utils/schlib/autogen/connector/)
J9 | 1 | VCC_Test | Conn_01x01 | Connector_Pin:Pin_D1.2mm_L10.2mm_W2.9mm_FlatFork | Generic connector, single row, 01x01, script generated (kicad-library-utils/schlib/autogen/connector/)
J10 | 1 | GNDD_Test | Conn_01x01 | Connector_Pin:Pin_D1.2mm_L10.2mm_W2.9mm_FlatFork | Generic connector, single row, 01x01, script generated (kicad-library-utils/schlib/autogen/connector/)
J11, J12 | 2 | GNDA_Test | Conn_01x01 | Connector_Pin:Pin_D1.2mm_L10.2mm_W2.9mm_FlatFork | Generic connector, single row, 01x01, script generated (kicad-library-utils/schlib/autogen/connector/)
J13 | 1 | Conn_01x03_Socket | Conn_01x03_Socket | Connector_PinSocket_2.54mm:PinSocket_1x03_P2.54mm_Horizontal | Generic connector, single row, 01x03, script generated
JP1 | 1 | Star_Ground | SolderJumper_3_Open |  | Solder Jumper, 3-pole, open
LED1 | 1 | Power_Led | LED | LED_THT:LED_D5.0mm | Light emitting diode
LED2 | 1 | Green_Led | LED | LED_THT:LED_D5.0mm | Light emitting diode
LED3 | 1 | Orange_Led | LED | LED_THT:LED_D5.0mm | Light emitting diode
LED4 | 1 | Red_Led | LED | LED_THT:LED_D5.0mm | Light emitting diode
P1 | 1 | Power | Conn_01x08 | Connector_PinSocket_2.54mm:PinSocket_1x08_P2.54mm_Vertical | Generic connector, single row, 01x08, script generated (kicad-library-utils/schlib/autogen/connector/)
P2 | 1 | Digital/PWM | Conn_01x10 | Connector_PinSocket_2.54mm:PinSocket_1x10_P2.54mm_Vertical | Generic connector, single row, 01x10, script generated (kicad-library-utils/schlib/autogen/connector/)
P3 | 1 | Analog | Conn_01x06 | Connector_PinSocket_2.54mm:PinSocket_1x06_P2.54mm_Vertical | Generic connector, single row, 01x06, script generated (kicad-library-utils/schlib/autogen/connector/)
P4 | 1 | Digital/PWM | Conn_01x08 | Connector_PinSocket_2.54mm:PinSocket_1x08_P2.54mm_Vertical | Generic connector, single row, 01x08, script generated (kicad-library-utils/schlib/autogen/connector/)
R1, R2 | 2 | 1k | R | Resistor_THT:R_Axial_DIN0207_L6.3mm_D2.5mm_P10.16mm_Horizontal | Resistor
R3, R5 | 2 | 33k | R | Resistor_THT:R_Axial_DIN0207_L6.3mm_D2.5mm_P10.16mm_Horizontal | Resistor
R4 | 1 | 220k | R | Resistor_THT:R_Axial_DIN0207_L6.3mm_D2.5mm_P10.16mm_Horizontal | Resistor
R6 | 1 | 100k | R | Resistor_THT:R_Axial_DIN0207_L6.3mm_D2.5mm_P10.16mm_Horizontal | Resistor
R7 | 1 | 100 | R | Resistor_THT:R_Axial_DIN0207_L6.3mm_D2.5mm_P10.16mm_Horizontal | Resistor
R8, R9, R10, R11 | 4 | 560 | R | Resistor_THT:R_Axial_DIN0207_L6.3mm_D2.5mm_P10.16mm_Horizontal | Resistor
SW1 | 1 | SW_Push | SW_Push | Button_Switch_THT:SW_DIP_SPSTx02_Slide_6.7x6.64mm_W7.62mm_P2.54mm_LowProfile | Push button switch, generic, two pins
U1, U2 | 2 | OPA340P | OPA340P | Package_DIP:DIP-8_W7.62mm | Single Single-Supply, Rail-to-Rail Operational Amplifier, MicroAmplifier Series, DIP-8

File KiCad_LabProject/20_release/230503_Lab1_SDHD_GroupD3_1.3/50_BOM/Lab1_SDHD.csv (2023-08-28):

Source: | C:\HDA_Courses\Sem2\SDHD\Labor\LabProject\40_Implementation\10_HW\XX_PCB_template\10_work\80_ProjectFiles\Lab1_SDHD\Lab1_SDHD.kicad_sch
Date: | 28-04-2023 23:34:32
Tool: | Eeschema 7.0.1
Generator: | C:\Program Files\KiCad\7.0\bin\scripting\plugins/bom_csv_grouped_by_value_with_fp.py
Component Count: | 39
Ref | Qnty | Value | Cmp name | Footprint | Description | Vendor | DNP
C1 | 1 | 22u | C_Polarized | Capacitor_THT:CP_Radial_D5.0mm_P2.50mm | Polarized capacitor
C2, C5 | 2 | 4.7u | C_Polarized | Capacitor_THT:CP_Radial_D6.3mm_P2.50mm | Polarized capacitor
C3 | 1 | 1.5n | C | Capacitor_THT:C_Rect_L7.2mm_W7.2mm_P5.00mm_FKS2_FKP2_MKS2_MKP2 | Unpolarized capacitor
C4 | 1 | 100n | C | Capacitor_THT:C_Rect_L7.2mm_W2.5mm_P5.00mm_FKS2_FKP2_MKS2_MKP2 | Unpolarized capacitor
C6 | 1 | 3.3n | C | Capacitor_THT:C_Rect_L7.2mm_W7.2mm_P5.00mm_FKS2_FKP2_MKS2_MKP2 | Unpolarized capacitor
J1, J2 | 2 | ~ | Conn_01x01 | Connector_PinHeader_2.54mm:PinHeader_1x01_P2.54mm_Vertical | Generic connector, single row, 01x01, script generated (kicad-library-utils/schlib/autogen/connector/)
J3 | 1 | IN1 | Conn_01x01 | Connector_PinHeader_2.54mm:PinHeader_1x01_P2.54mm_Vertical | Generic connector, single row, 01x01, script generated (kicad-library-utils/schlib/autogen/connector/)
J4 | 1 | IN2 | Conn_01x01 | Connector_PinHeader_2.54mm:PinHeader_1x01_P2.54mm_Vertical | Generic connector, single row, 01x01, script generated (kicad-library-utils/schlib/autogen/connector/)
J5 | 1 | OUT1 | Conn_01x01 | Connector_PinHeader_2.54mm:PinHeader_1x01_P2.54mm_Vertical | Generic connector, single row, 01x01, script generated (kicad-library-utils/schlib/autogen/connector/)
J6 | 1 | IN3 | Conn_01x01 | Connector_PinHeader_2.54mm:PinHeader_1x01_P2.54mm_Vertical | Generic connector, single row, 01x01, script generated (kicad-library-utils/schlib/autogen/connector/)
J7 | 1 | OUT2 | Conn_01x01 | Connector_PinHeader_2.54mm:PinHeader_1x01_P2.54mm_Vertical | Generic connector, single row, 01x01, script generated (kicad-library-utils/schlib/autogen/connector/)
J8 | 1 | Vout | Conn_01x01 | Connector_PinHeader_2.54mm:PinHeader_1x01_P2.54mm_Vertical | Generic connector, single row, 01x01, script generated (kicad-library-utils/schlib/autogen/connector/)
J9 | 1 | +5V_Test | Conn_01x01 | Connector_PinHeader_2.54mm:PinHeader_1x01_P2.54mm_Vertical | Generic connector, single row, 01x01, script generated (kicad-library-utils/schlib/autogen/connector/)
J10 | 1 | GND_Test | Conn_01x01 | Connector_PinHeader_2.54mm:PinHeader_1x01_P2.54mm_Vertical | Generic connector, single row, 01x01, script generated (kicad-library-utils/schlib/autogen/connector/)
J11 | 1 | Conn_01x03_Socket | Conn_01x03_Socket | Connector_PinSocket_2.54mm:PinSocket_1x03_P2.54mm_Horizontal | Generic connector, single row, 01x03, script generated
LED1 | 1 | Power_Led | LED | LED_THT:LED_D5.0mm | Light emitting diode
LED2 | 1 | Green_Led | LED | LED_THT:LED_D5.0mm | Light emitting diode
LED3 | 1 | Orange_Led | LED | LED_THT:LED_D5.0mm | Light emitting diode
LED4 | 1 | Red_Led | LED | LED_THT:LED_D5.0mm | Light emitting diode
P1 | 1 | Power | Conn_01x08 | Connector_PinSocket_2.54mm:PinSocket_1x08_P2.54mm_Vertical | Generic connector, single row, 01x08, script generated (kicad-library-utils/schlib/autogen/connector/)
P2 | 1 | Digital/PWM | Conn_01x10 | Connector_PinSocket_2.54mm:PinSocket_1x10_P2.54mm_Vertical | Generic connector, single row, 01x10, script generated (kicad-library-utils/schlib/autogen/connector/)
P3 | 1 | Analog | Conn_01x06 | Connector_PinSocket_2.54mm:PinSocket_1x06_P2.54mm_Vertical | Generic connector, single row, 01x06, script generated (kicad-library-utils/schlib/autogen/connector/)
P4 | 1 | Digital/PWM | Conn_01x08 | Connector_PinSocket_2.54mm:PinSocket_1x08_P2.54mm_Vertical | Generic connector, single row, 01x08, script generated (kicad-library-utils/schlib/autogen/connector/)
R1, R2 | 2 | 1k | R | Resistor_THT:R_Axial_DIN0207_L6.3mm_D2.5mm_P10.16mm_Horizontal | Resistor
R3 | 1 | 2.2k | R | Resistor_THT:R_Axial_DIN0207_L6.3mm_D2.5mm_P10.16mm_Horizontal | Resistor
R4 | 1 | 220k | R | Resistor_THT:R_Axial_DIN0207_L6.3mm_D2.5mm_P10.16mm_Horizontal | Resistor
R5 | 1 | 33k | R | Resistor_THT:R_Axial_DIN0207_L6.3mm_D2.5mm_P10.16mm_Horizontal | Resistor
R6 | 1 | 100k | R | Resistor_THT:R_Axial_DIN0207_L6.3mm_D2.5mm_P10.16mm_Horizontal | Resistor
R7 | 1 | 100 | R | Resistor_THT:R_Axial_DIN0207_L6.3mm_D2.5mm_P10.16mm_Horizontal | Resistor
R8, R9, R10, R11 | 4 | 470 | R | Resistor_THT:R_Axial_DIN0207_L6.3mm_D2.5mm_P10.16mm_Horizontal | Resistor
SW1 | 1 | SW_Push | SW_Push | Button_Switch_THT:SW_PUSH_6mm_H7.3mm | Push button switch, generic, two pins
U1, U2 | 2 | OPA340P | OPA340P | Package_DIP:DIP-8_W7.62mm_Socket | Single Single-Supply, Rail-to-Rail Operational Amplifier, MicroAmplifier Series, DIP-8

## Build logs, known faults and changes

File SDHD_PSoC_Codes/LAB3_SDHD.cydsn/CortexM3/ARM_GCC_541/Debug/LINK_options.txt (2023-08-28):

-Wl,--start-group -o "C:\\Users\\giris\\OneDrive\\Documents\\PSoC\ Creator\\SDHD\\LAB3_SDHD.cydsn\\CortexM3\\ARM_GCC_541\\Debug\\LAB3_SDHD.elf" ".\\CortexM3\\ARM_GCC_541\\Debug\\main.o" ".\\CortexM3\\ARM_GCC_541\\Debug\\logging.o" ".\\CortexM3\\ARM_GCC_541\\Debug\\cyfitter_cfg.o" ".\\CortexM3\\ARM_GCC_541\\Debug\\cymetadata.o" ".\\CortexM3\\ARM_GCC_541\\Debug\\Cm3Start.o" ".\\CortexM3\\ARM_GCC_541\\Debug\\LAB3_SDHD.a" "C:\\Program\ Files\ (x86)\\Cypress\\PSoC\ Creator\\4.4\\PSoC\ Creator\\psoc\\content\\cycomponentlibrary\\CyComponentLibrary.cylib\\CortexM3\\ARM_GCC_541\\Debug\\CyComponentLibrary.a" -mcpu=cortex-m3 -mthumb -L "Generated_Source\\PSoC5" "-Wl,-Map,.\\CortexM3\\ARM_GCC_541\\Debug/LAB3_SDHD.map" -T "Generated_Source\\PSoC5\\cm3gcc.ld" -specs=nano.specs -Wl,--gc-sections -g -ffunction-sections -Og -ffat-lto-objects -Wl,--end-group

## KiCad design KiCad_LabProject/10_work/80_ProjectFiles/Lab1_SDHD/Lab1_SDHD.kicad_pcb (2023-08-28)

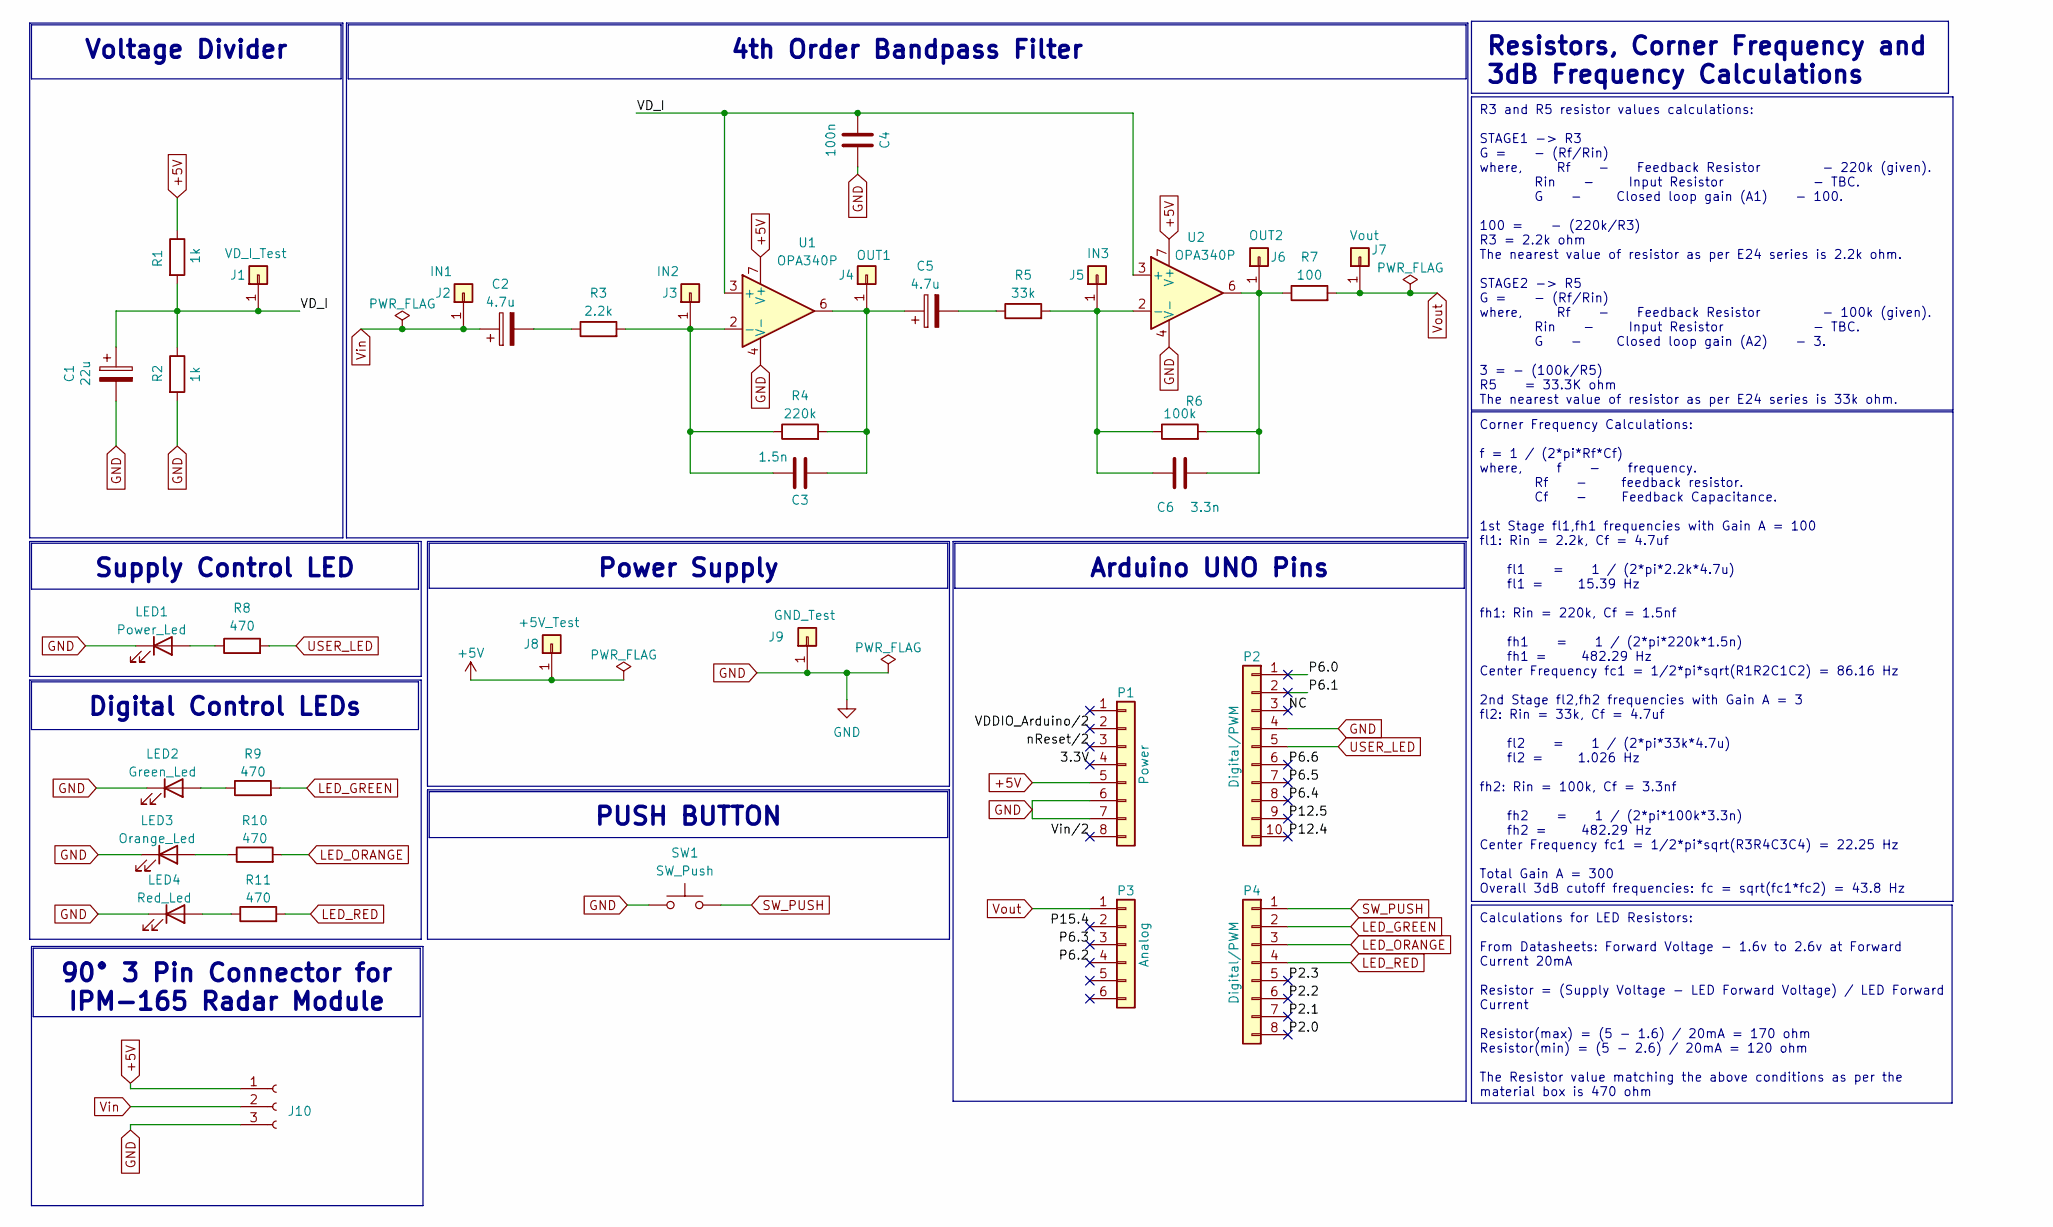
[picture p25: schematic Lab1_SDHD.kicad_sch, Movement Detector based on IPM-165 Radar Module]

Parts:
C1: 22u; CP_Radial_D5.0mm_P2.50mm
C2, C5: 4.7u; CP_Radial_D6.3mm_P2.50mm
C3: 1.5n; C_Rect_L7.2mm_W7.2mm_P5.00mm_FKS2_FKP2_MKS2_MKP2
C4: 100n; C_Rect_L7.2mm_W2.5mm_P5.00mm_FKS2_FKP2_MKS2_MKP2
C6: 3.3n; C_Rect_L7.2mm_W7.2mm_P5.00mm_FKS2_FKP2_MKS2_MKP2
J1: VD_I_Test; PinHeader_1x01_P2.54mm_Vertical
J2: IN1; PinHeader_1x01_P2.54mm_Vertical
J3: IN2; PinHeader_1x01_P2.54mm_Vertical
J4: OUT1; PinHeader_1x01_P2.54mm_Vertical
J5: IN3; PinHeader_1x01_P2.54mm_Vertical
J6: OUT2; PinHeader_1x01_P2.54mm_Vertical
J7: Vout; PinHeader_1x01_P2.54mm_Vertical
J8: +5V_Test; PinHeader_1x01_P2.54mm_Vertical
J9: GND_Test; PinHeader_1x01_P2.54mm_Vertical
J10: Conn_01x03_Socket; PinSocket_1x03_P2.54mm_Horizontal_NEW
LED1: Power_Led; LED_D5.0mm
LED2: Green_Led; LED_D5.0mm
LED3: Orange_Led; LED_D5.0mm
LED4: Red_Led; LED_D5.0mm
P1: Power; PinHeader_1x08_P2.54mm_Vertical
P2: Digital/PWM; PinHeader_1x10_P2.54mm_Vertical
P3: Analog; PinHeader_1x06_P2.54mm_Vertical
P4: Digital/PWM; PinHeader_1x08_P2.54mm_Vertical_New
R1, R2: 1k; R_Axial_DIN0207_L6.3mm_D2.5mm_P10.16mm_Horizontal
R3: 2.2k; R_Axial_DIN0207_L6.3mm_D2.5mm_P10.16mm_Horizontal
R4: 220k; R_Axial_DIN0207_L6.3mm_D2.5mm_P10.16mm_Horizontal
R5: 33k; R_Axial_DIN0207_L6.3mm_D2.5mm_P10.16mm_Horizontal
R6: 100k; R_Axial_DIN0207_L6.3mm_D2.5mm_P10.16mm_Horizontal
R7: 100; R_Axial_DIN0207_L6.3mm_D2.5mm_P10.16mm_Horizontal
R8, R9, R10, R11: 470; R_Axial_DIN0207_L6.3mm_D2.5mm_P10.16mm_Horizontal
SW1: SW_Push; SW_PUSH_6mm_H7.3mm
U1, U2: OPA340P; DIP-8_W7.62mm_Socket

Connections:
+5V: J8.1, J10.1, P1.5, R1.1, U1.7 (V+), U2.7 (V+)
/3.3V: P1.4
/NC: P2.3
/P2.0: P4.8
/P2.1: P4.7
/P2.2: P4.6
/P2.3: P4.5
/P6.0: P2.1
/P6.1: P2.2
/P6.2: P3.4
/P6.3: P3.3
/P6.4: P2.8
/P6.5: P2.7
/P6.6: P2.6
/P12.4: P2.10
/P12.5: P2.9
/P15.4: P3.2
/VDDIO_Arduino/2: P1.2
/VD_I: C1.1, C4.2, J1.1, R1.2, R2.1, U1.3 (+), U2.3 (+)
/Vin/2: P1.8
/nReset/2: P1.3
GND: C1.2, C4.1, J9.1, J10.3, LED1.1 (K), LED2.1 (K), LED3.1 (K), LED4.1 (K), P1.6, P1.7, P2.4, R2.2, SW1.1, U1.4 (V-), U2.4 (V-)
LED_GREEN: P4.2, R9.2
LED_ORANGE: P4.3, R10.2
LED_RED: P4.4, R11.2
unnamed: C2.2, R3.1
unnamed: C5.2, R5.1
unnamed: C3.1, J3.1, R3.2, R4.1, U1.2 (-)
unnamed: C3.2, C5.1, J4.1, R4.2, U1.6
unnamed: C6.1, J5.1, R5.2, R6.1, U2.2 (-)
unnamed: C6.2, J6.1, R6.2, R7.1, U2.6
unnamed: LED1.2 (A), R8.1
unnamed: LED2.2 (A), R9.1
unnamed: LED3.2 (A), R10.1
unnamed: LED4.2 (A), R11.1
SW_PUSH: P4.1, SW1.2
USER_LED: P2.5, R8.2
Vin: C2.1, J2.1, J10.2
Vout: J7.1, P3.1, R7.2

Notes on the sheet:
Power Supply
90° 3 Pin Connector for IPM-165 Radar Module
R3 and R5 resistor values calculations: STAGE1 -> R3 G = - (Rf/Rin) where, Rf - Feedback Resistor - 220k (given). Rin - Input Resistor - TBC. G - Closed loop gain (A1) - 100. 100 = - (220k/R3) R3 = 2.2k ohm The nearest value of resistor as per E24 series is 2.2k ohm. STAGE2 -> R5 G = - (Rf/Rin) whe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
Arduino UNO Pins
Corner Frequency Calculations: f = 1 / (2*pi*Rf*Cf) where, f - frequency. Rf - feedback resistor. Cf - Feedback Capacitance. 1st Stage fl1,fh1 frequencies with Gain A = 100 fl1: Rin = 2.2k, Cf = 4.7uf fl1 = 1 / (2*pi*2.2k*4.7u) fl1 = 15.39 Hz fh1: Rin = 220k, Cf = 1.5nf fh1 = 1 / (2*pi*220k*1.5n) f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
Calculations for LED Resistors: From Datasheets: Forward Voltage - 1.6v to 2.6v at Forward Current 20mA Resistor = (Supply Voltage - LED Forward Voltage) / LED Forward Current Resistor(max) = (5 - 1.6) / 20mA = 170 ohm Resistor(min) = (5 - 2.6) / 20mA = 120 ohm The Resistor value matching the above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
4th Order Bandpass Filter
Voltage Divider
Resistors, Corner Frequency and 3dB Frequency Calculations
Supply Control LED
Digital Control LEDs
PUSH BUTTON

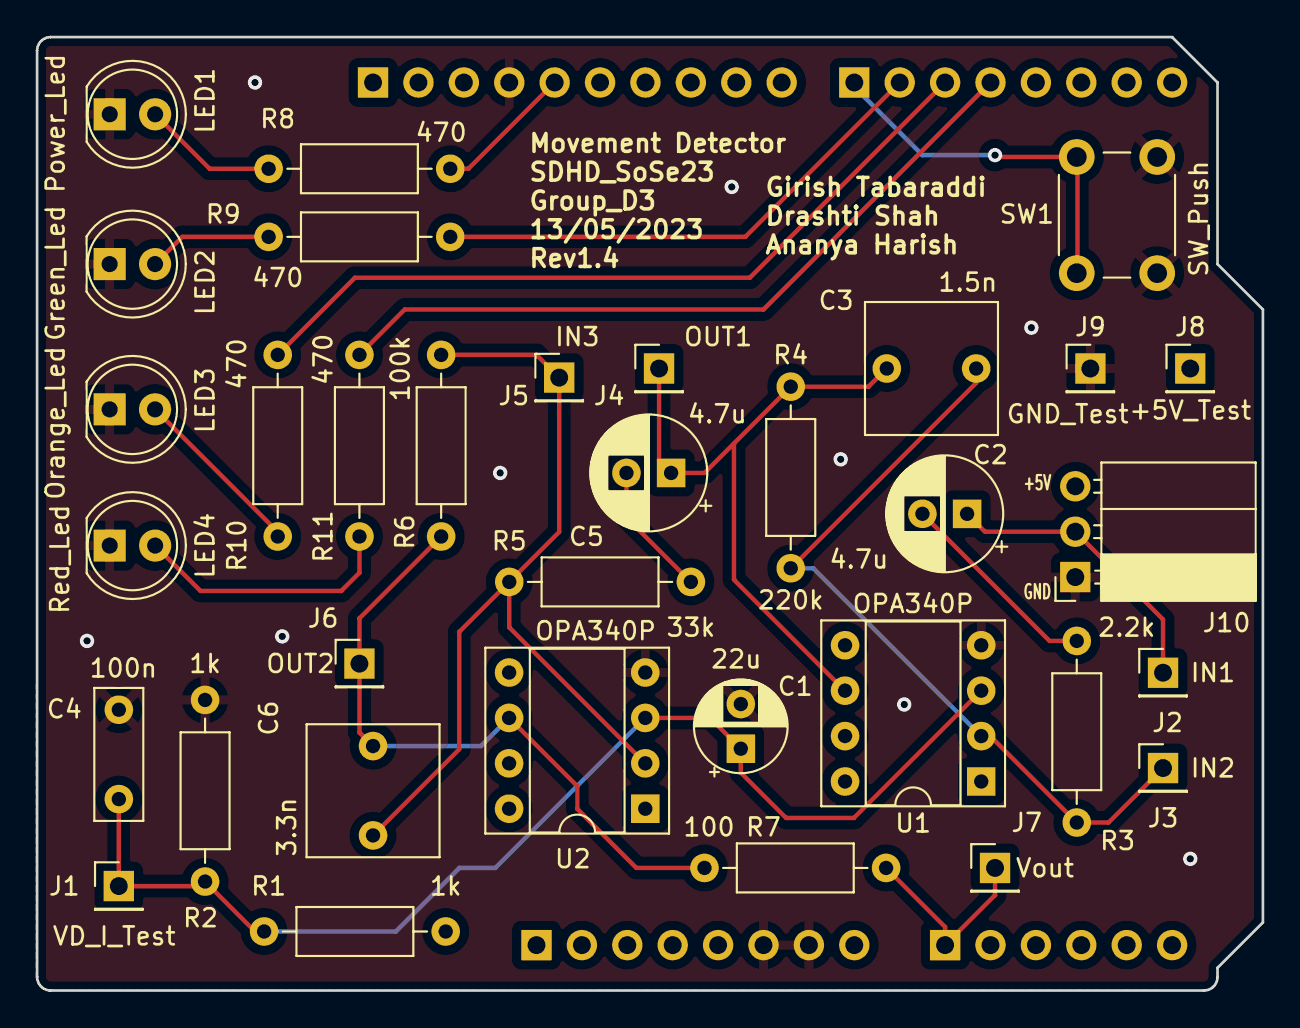
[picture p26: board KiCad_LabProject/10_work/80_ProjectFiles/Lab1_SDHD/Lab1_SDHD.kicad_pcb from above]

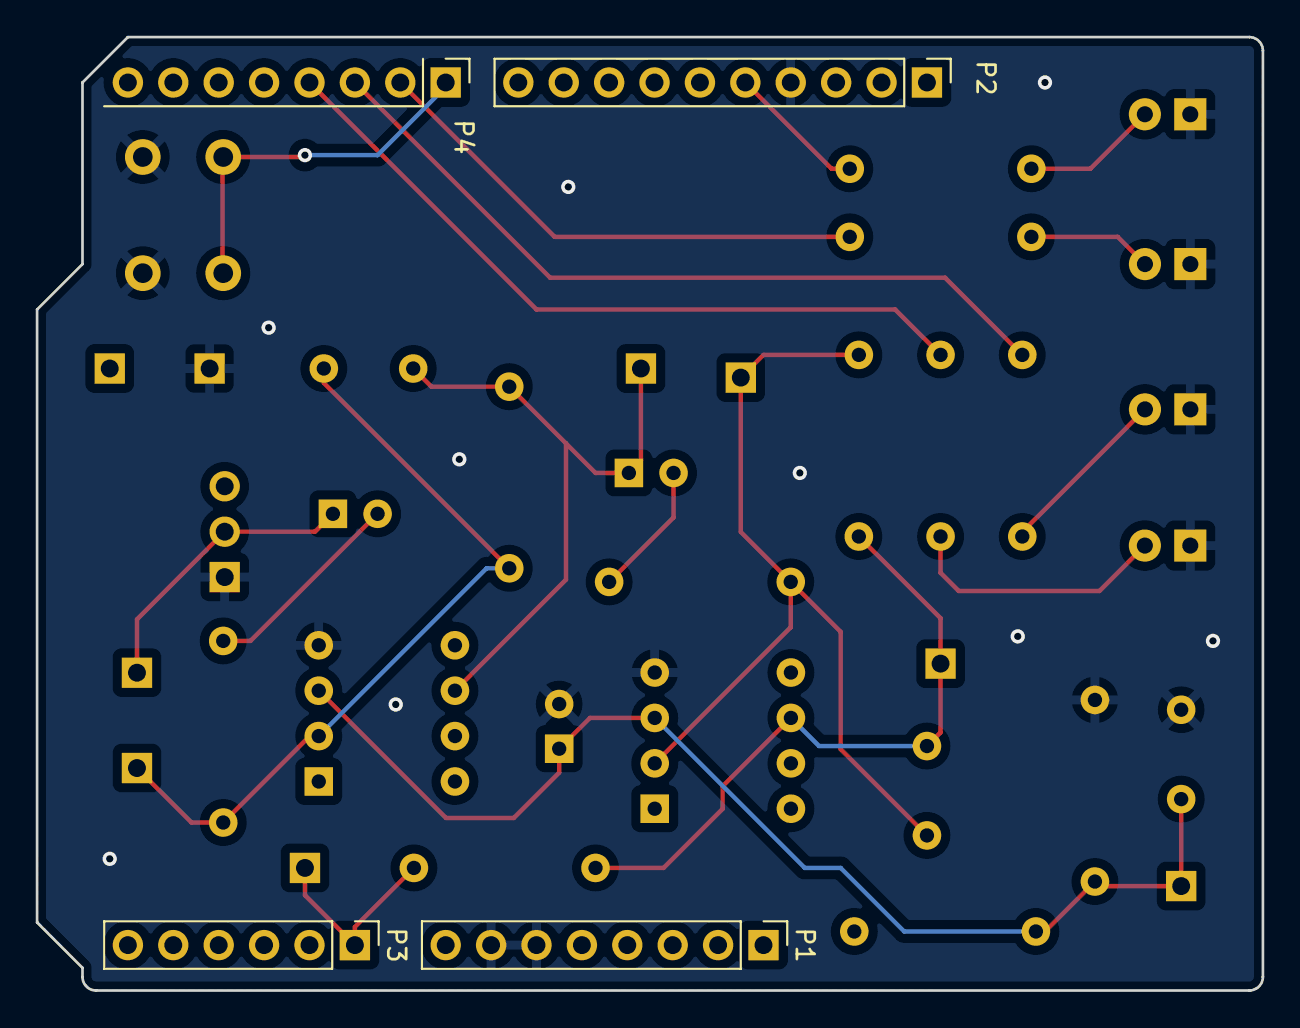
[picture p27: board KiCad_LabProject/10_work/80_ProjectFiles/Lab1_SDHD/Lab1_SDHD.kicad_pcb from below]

Board: 4 copper layers, 68.6 x 53.3 mm, 38 parts (4 on the bottom side), 20 nets.

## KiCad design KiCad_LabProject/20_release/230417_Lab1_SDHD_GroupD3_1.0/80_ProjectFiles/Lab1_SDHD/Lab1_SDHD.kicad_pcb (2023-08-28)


Board: 2 copper layers, 68.6 x 53.3 mm, 8 parts (0 on the bottom side), 3 nets, no tracks yet.

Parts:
J1: Power; PinSocket_1x08_P2.54mm_Vertical
J2: Digital/PWM; PinSocket_1x10_P2.54mm_Vertical
J3: Analog; PinSocket_1x06_P2.54mm_Vertical
J4: Digital/PWM; PinSocket_1x08_P2.54mm_Vertical
MH1, MH2, MH3, MH4: MountingHole_3.2mm

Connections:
/SCL/A5: J2.1, J3.6
/SDA/A4: J2.2, J3.5
GND: J1.6, J1.7, J2.4

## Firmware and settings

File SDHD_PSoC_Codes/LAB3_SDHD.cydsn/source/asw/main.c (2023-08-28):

/* ========================================
 *
 * Copyright YOUR COMPANY, THE YEAR
 * All Rights Reserved
 * UNPUBLISHED, LICENSED SOFTWARE.
 *
 * CONFIDENTIAL AND PROPRIETARY INFORMATION
 * WHICH IS THE PROPERTY OF your company.
 *
 * ========================================
*/
#include <stdio.h>
#include <stdlib.h>
#include "project.h"
#include "logging.h"

volatile uint8 toggle = 0;

CY_ISR_PROTO(isr_button_RisingEdge_Interrupt);

CY_ISR_PROTO(isr_UART);

typedef enum
{
    IDLE_STATE,
    SAMPLING_STATE,
    UART_TRANSFER_STATE

}STATE_t;

uint8_t sChRx = 0;
uint8_t oChRx = 0;
char rxDataCh;

int main(void)
{
    CyGlobalIntEnable; /* Enable global interrupts. */
    
    isr_button_StartEx(isr_button_RisingEdge_Interrupt);
    isr_UART_StartEx(isr_UART);
    
    //Hardware Init
    UART_LOG_Start();
    WaveDAC8_Start();
    //WaveDAC8_Enable();
    ADC_Start();
    ADC_StartConvert();
    
    //char buffer[100];
    
    uint8_t count = 0;
    uint16_t ADC_Array[1024] = {0};
    
    /* Place your initialization/startup code here (e.g. MyInst_Start()) */
    
    //Initializing the state to IDLE_STATE.
    STATE_t POS = IDLE_STATE;
 
    for(; ;)
    {
        switch(POS)
        {
            case IDLE_STATE:
                //Initializing count to 0;
                count = 0;
                if(toggle == 1)
                {
                    POS = SAMPLING_STATE;
                    toggle = 0;
                }
            break;
            
            case SAMPLING_STATE:
                for(int i = 0; i < 1024; i++)
                {
                    ADC_IsEndConversion(ADC_WAIT_FOR_RESULT);
                    
                 //   int32 ADC_result = ADC_GetResult32();
        //            ADC_Array[i] = (uint16_t)ADC_CountsTo_mVolts(ADC_result);
                    ADC_Array[i] = (uint16_t)ADC_GetResult32();
//                    itoa(ADC_result_mV, buffer, 10);
//                    UART_LOG_PutString(buffer);
//                    UART_LOG_PutString("\n");
                }
                
//                if(UART_LOG_GetChar() == 's')
//                {
//                    Red_LED_Write(1);
//                    POS = UART_TRANSFER_STATE;
//                }
                         
                if(sChRx)
                {
                 //   UART_LOG_PutString("I received S \n");
                    Red_LED_Write(1);
                    POS = UART_TRANSFER_STATE;
                    sChRx = 0;
                }
            break;
            
            case UART_TRANSFER_STATE:
                for(int i = 0; i < 1024; i++)
                {
                    UART_LOG_PutChar(ADC_Array[i]);
                    UART_LOG_PutChar(ADC_Array[i]>>8);
                }
                count++;
                
//                if((count < 10) && UART_LOG_GetChar() == 'o')
//                {
//                    POS = SAMPLING_STATE;
//                    Red_LED_Write(0);
//                }
//                else if((count == 10) && UART_LOG_GetChar() == 'o')
//                {
//                    POS = IDLE_STATE;  
//                }
                
                if((count < 10) && oChRx)
                {
                    POS = SAMPLING_STATE;
                    Red_LED_Write(0);
                    oChRx = 0;
                }
                else if((count == 10) && oChRx)
                {
                    POS = IDLE_STATE;  
                    oChRx = 0;
                }
            break;
            
            default:
            break;
        }
    }
}
    
/**
*This interrupt service routine will be called whenever a Button 1 rising edge interrupt occurs.
**/
CY_ISR(isr_button_RisingEdge_Interrupt)
{
    Push_button_ClearInterrupt();
    
    if(toggle == 0)
    {
        toggle = 1;
    }
}

CY_ISR(isr_UART)
{
    rxDataCh = UART_LOG_GetChar();
    if(rxDataCh == 's')
    {
       // UART_LOG_PutString("S is sent \n");
        sChRx = 1;
    }
    if(rxDataCh == 'o')
    {
        oChRx = 1;
    }
}
/* [] END OF FILE */

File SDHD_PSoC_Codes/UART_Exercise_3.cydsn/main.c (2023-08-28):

/* ========================================
 *
 * Copyright YOUR COMPANY, THE YEAR
 * All Rights Reserved
 * UNPUBLISHED, LICENSED SOFTWARE.
 *
 * CONFIDENTIAL AND PROPRIETARY INFORMATION
 * WHICH IS THE PROPERTY OF your company.
 *
 * ========================================
*/
#include "project.h"
#include "stdlib.h"

#define METHOD_1_Traingular_Wave    0
#define METHOD_2_Traingular_Wave    0
#define METHOD_1_Saw_Tooth_Wave     0
#define METHOD_2_Saw_Tooth_Wave     0
#define METHOD_1_Step_Signal        0
#define METHOD_1_Square_Signal      0

#define METHOD_chatgpt 0

int main(void)
{
    CyGlobalIntEnable; /* Enable global interrupts. */

    UART_LOG_Start();
    
    //UART_LOG_PutString("Hello PSoC Exercise 3");  // UART Debug statement to check if it is started
    
    uint16_t waveform_array[256] = {0}; // An 256 size array to store the values required to plot waveforms.
    
    
#ifdef METHOD_1_Traingular_Wave
   
//    for(uint16_t i = 0; i < 129; i++)
//    {
//        waveform_array[i] = i;
//              
//    }
//    for(uint16_t i = 129; i < 255; i++)
//    {
//        waveform_array[i] = 255 - i;  
//    }
#endif
    
#ifdef METHOD_2_Traingular_Wave
  
//    for(uint16_t i = 0; i < 256; i++)
//    {
//        waveform_array[i] = i;
//        
//        if(i > 129)
//        {
//            waveform_array[i] = 255 - i;
//        }
//              
//    } 
#endif

#ifdef METHOD_1_Saw_Tooth_Wave
   
//    for(uint16_t i = 0; i < 129; i++)
//    {
//        waveform_array[i] = i;
//              
//    }
//    for(uint16_t i = 1; i < 127; i++)
//    {
//        waveform_array[128 + i] = 128+i;  
//    }
#endif

#ifdef METHOD_2_Saw_Tooth_Wave

//    uint16_t interval = 64; // The interval at which to repeat the saw tooth waveform pattern
//    
//    for (uint16_t j = 0; j < 256; j += interval)
//    {
//        for (uint16_t i = 0; i < interval; i++)
//        {
//            waveform_array[j + i] = i;
//            waveform_array[j + interval + i] = interval - i - 1;
//        }
//    }
#endif
    
#ifdef METHOD_1_Step_Signal
    
//    uint16_t interval = 64; // The interval at which to place the steps
//    
//    for (uint16_t i = 0; i < 256; i += interval)
//    {
//        for (uint16_t j = 0; j < interval; j++)
//        {
//            waveform_array[i + j] = i;
//        }
//    }
#endif

#ifdef METHOD_1_Square_Signal
    
//    uint16_t period = 128; // The period of the square wave
//    uint16_t interval = 64; // Half of the period
//    
//    // Generate the square wave with a period of 128 samples
//    for (uint16_t i = 0; i < 256; i++)
//    {
//        if ((i % period) < interval)
//        {
//            waveform_array[i] = 255;
//        }
//        else
//        {
//            waveform_array[i] = 0;
//        }
//    }
#endif
    /* Place your initialization/startup code here (e.g. MyInst_Start()) */

    for(;;)
    {
        /* Place your application code here. */
        if(UART_LOG_GetChar() == 's')
        {
            for(uint16_t i = 0; i < 256; i++)
            {
                UART_LOG_PutChar(waveform_array[i]);
            }
        }
    }
}

/* [] END OF FILE */

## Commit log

2023-08-28 adding Kicad files to the feature branch
    [HW_BOM_project.xls, HW_BOM_project.xlsx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]
2023-08-28 adding psoc project codes to the feature branch
    [3bitCounter.sdf, ADC_Exercise.sdf, Button.sdf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]

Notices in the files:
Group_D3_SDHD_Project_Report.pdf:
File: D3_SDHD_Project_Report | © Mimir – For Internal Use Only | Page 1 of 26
